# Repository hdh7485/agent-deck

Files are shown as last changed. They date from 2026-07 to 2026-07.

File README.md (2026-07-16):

# Agent Deck

Codex, Hermes, OMX, tmux 같은 AI 에이전트 작업을 물리적으로 제어하고 상태를 RGB로 표시하는 데스크톱 컨트롤러 프로젝트입니다.

이 프로젝트는 공개된 제품 경험을 참고하되, 공개되지 않은 OpenAI Micro의 회로·펌웨어·프로토콜을 추정하거나 복제하지 않습니다. 목표는 기능적으로 유사한 사용자 경험을 제공하는 독자 설계입니다.

## V1 범위

- PCB 고정형 MX 호환 기계식 키 12개, Kailh 핫스왑 소켓, 키별 다이오드. 터치 오른쪽 K11은 기본 2u 마이크/PTT 키
- 전체 12키 개별 RGB 상태 표시
- 클릭 가능한 로터리 엔코더 1개
- 낮은 원형 오목 캡을 씌운 5방향 디지털 내비게이션 스위치 1개
- 단일 원형 정전식 터치 패드 1개
- XIAO ESP32-S3 Plus와 XIAO nRF52840 Plus 비교 평가
- USB HID, Vendor HID, BLE HID 및 상태 통신 실험
- Codex/Hermes/OMX/tmux 상태를 정규화하는 PC 브리지
- USB 전원 우선 검증 후 1셀 Li-Po 평가

OLED나 LCD는 사용하지 않습니다. 모든 입력 부품은 브레드보드가 아니라 입력 PCB에 직접 실장합니다.

## 현재 기준 설계

V1은 공용 입력 PCB와 MCU별 어댑터 보드를 사용합니다. 입력 PCB에는 키 매트릭스, MCP23017, 내비게이션 스위치, 정전식 터치 IC, 엔코더, RGB LED 및 전원 보호 회로를 두고, 어댑터는 XIAO 보드별 핀·전원·USB 차이를 흡수합니다.

- 키 12개: 5핀 MX 호환 스위치, Kailh `CPG151101S11-16` 핫스왑 소켓, 다이오드를 포함한 4×4 매트릭스. K11은 호스트 음성 입력을 누르는 동안만 여는 기본 PTT 매핑
- MCP23017: 키 매트릭스, 5방향 스위치, 터치 출력 처리
- 엔코더 A/B/클릭: MCU 직접 연결
- 터치: AT42QT1010 계열 외부 IC 우선
- RGB: 5V 주소 지정 LED, 74AHCT1G125 레벨 시프터, 전류 제한 전원 스위치
- USB-C: V1에서는 장착한 XIAO의 온보드 USB-C를 케이스 밖으로 노출
- 배터리: 어댑터 측에서 각 XIAO의 충전·배터리 회로를 사용하고 공용 PCB에 충전기를 중복하지 않음

이 결정은 회로도 작성 전 공식 회로도 대조와 벤치 실험으로 다시 검증합니다.

## KiCad V1 엔지니어링 드래프트

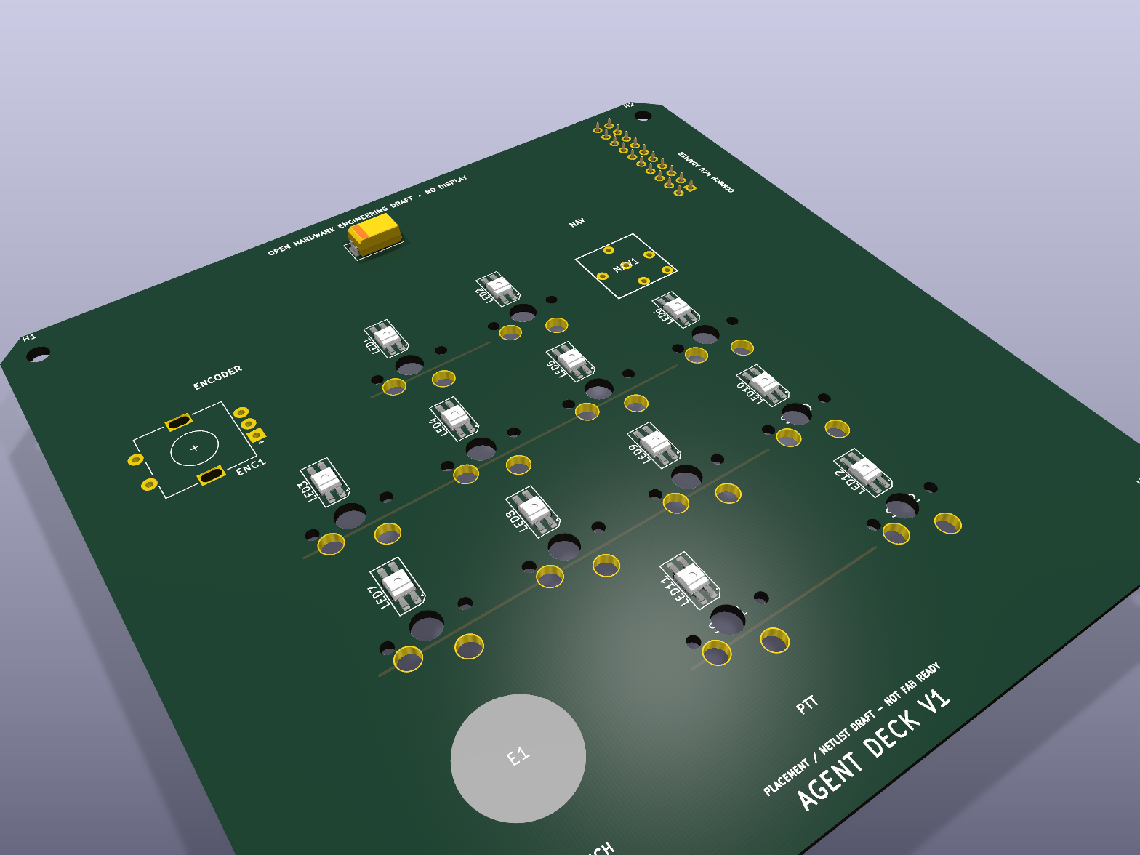
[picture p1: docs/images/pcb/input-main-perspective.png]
Agent Deck V1 common input PCB perspective


현재 저장소에는 다음 실제 KiCad 설계 소스가 있습니다.

- 공용 입력 PCB: 12키, 12다이오드, 키별 RGB 12개, MCP23017, EC11, 5방향 입력, AT42QT1010 터치, TPS2553 RGB 전류 제한, AHCT 레벨 시프터
- XIAO ESP32-S3 Plus 전용 어댑터
- XIAO nRF52840 Plus 전용 어댑터
- 세 보드의 블록 회로도와 재현 가능한 생성 스크립트

이 파일은 부품 배치와 전기 넷을 검토하기 위한 엔지니어링 드래프트입니다. 장거리 배선은 정확한 스위치·내비게이션·커넥터·플레이트 치수를 확정한 뒤 수동 라우팅하므로 아직 PCB 제작용 릴리스가 아닙니다. 현재 검증 결과와 남은 DRC 항목은 [KiCad 검증 기록](hardware/kicad/VALIDATION.md)에 있습니다.

## 3D 프린트 케이스 핏체크

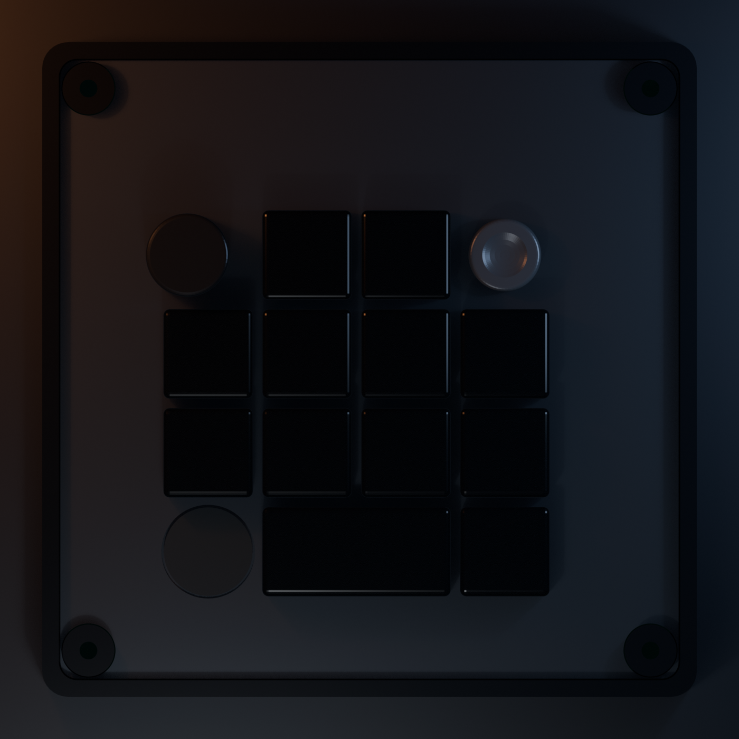
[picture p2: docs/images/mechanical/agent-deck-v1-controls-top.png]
Agent Deck V1 top control layout


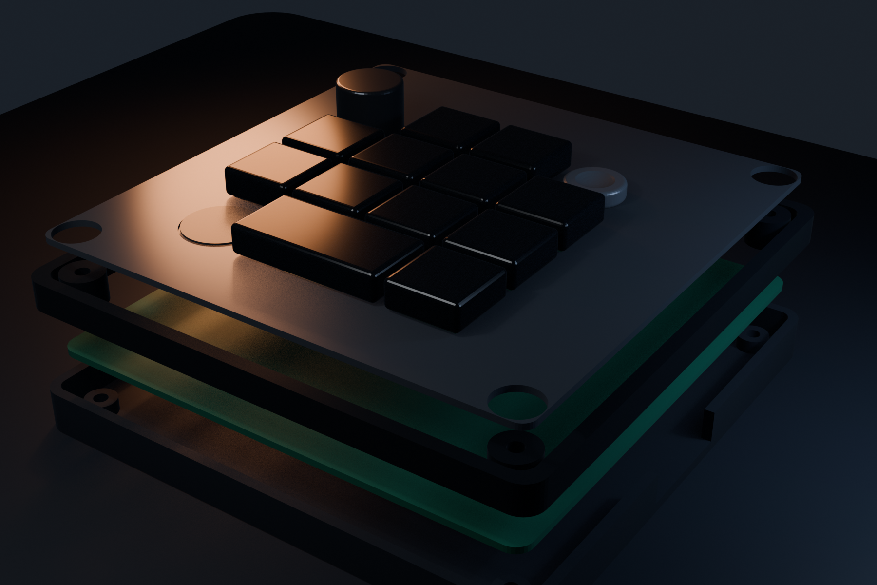
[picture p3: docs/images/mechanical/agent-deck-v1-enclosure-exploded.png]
Agent Deck V1 enclosure exploded view


현재 PCB 좌표에서 생성한 하판, 상부 베젤, 12키 1.5 mm MX 플레이트 STL이 `mechanical/exports/v1-fit-check/`에 있습니다. 공개 외형처럼 상단은 엔코더–키 2개–조이스틱, 하단은 터치–2u PTT–보조 키로 배치했습니다. 모든 키캡은 각인 없는 검정 반투명 스모크 재질을 의도하며, 1u와 2u 키를 19 mm 격자와 1.8 mm 명목 간격으로 정렬했습니다. 공용 PCB는 118 × 118 mm, 케이스 외형은 125.8 × 125.8 × 17.0 mm의 정사각형입니다. 정확한 2u 스태빌라이저·스위치·USB·배터리·터치 치수가 아직 확정되지 않았으므로 양산 케이스가 아니라 조립 간섭을 찾기 위한 출력용 초안입니다.

## 문서 지도

- [제품 요구사항](.omx/plans/prd-agent-deck-v1.md)
- [검증 계획](.omx/plans/test-spec-agent-deck-v1.md)
- [시스템 아키텍처](docs/architecture/system-architecture.md)
- [XIAO 핀 호환성](docs/hardware/pin-compatibility.md)
- [전기 설계 제안](docs/hardware/electrical-proposal.md)
- [부품·기구 결정 체크리스트](docs/hardware/design-inputs-checklist.md)
- [V1 프로토타입 BOM](docs/hardware/prototype-bom.csv)
- [장치 프로토콜](docs/protocol/device-protocol.md)
- [공식 자료 목록](docs/research/source-register.md)
- [KiCad 구조](hardware/kicad/README.md)
- [KiCad 검증 기록](hardware/kicad/VALIDATION.md)
- [펌웨어 구조](firmware/README.md)
- [PC 브리지 구조](bridge/README.md)
- [기구 설계 구조](mechanical/README.md)
- [3D 프린트 케이스 핏체크](mechanical/enclosure/README.md)

## 제작 순서

1. 두 MCU의 최소 펌웨어와 통신 경로를 개발 보드에서 검증
2. 공식 핀맵·회로도와 선택 부품 데이터시트로 회로도 작성
3. 입력 PCB와 MCU 어댑터 PCB 설계 및 DRC/ERC
4. 스위치 플레이트 설계
5. 케이스와 USB/안테나/배터리 간섭 검증
6. 조립 및 전기적 안전 검사
7. USB/BLE/입력/RGB/전력/재연결/위험 동작 E2E 테스트

## 상태

V1 공용 입력 PCB와 두 MCU 어댑터의 KiCad 엔지니어링 드래프트를 만들었고, 세 블록 회로도는 ERC를 통과했습니다. PCB는 배치·넷리스트 검토 단계이며 부품 규격을 잠근 뒤 수동 라우팅, DRC 정리, 플레이트/케이스 3D 간섭 검증을 진행해야 합니다. 펌웨어와 PC 브리지는 아직 구조 문서 단계입니다.

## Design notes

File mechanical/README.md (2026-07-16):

# Mechanical design structure

## Stack baseline

- Separate 1.5 mm MX switch/control plate for the V1 fit-check.
- Common input PCB, nominally 1.6 mm.
- MCU adapter below or beside the input PCB with the XIAO USB-C accessible from the enclosure.
- Enclosure support around encoder, navigation switch, USB connector, and other repeated-load parts.

## Proposed tree

```text
mechanical/
  references/      # manufacturer STEP/DXF with source notes
  plate/           # plate source and exports
  enclosure/       # top/bottom enclosure source and exports
  fixtures/        # assembly and touch/force test fixtures
  exports/         # release-only STEP/DXF/STL when versioned
```

## Locked constraints

- No OLED/LCD window.
- All keys, LEDs, encoder, navigation switch, and touch electrode originate from PCB coordinates.
- The plate or enclosure carries repeated encoder/navigation force instead of relying only on solder pads.
- RF antenna regions remain free of metal plate, battery, dense copper, and enclosure features that violate the board guidance.
- Reset/boot/SWD service access remains possible without destructive disassembly during V1.
- USB cable shell and strain envelope are modeled, not just the receptacle body.

## Dimensions required before CAD release

- Exact MX switch/keycap MPN, travel, and retention tolerance; family, 19 mm pitch, 14.2 mm cutout, and Kailh socket candidate are selected.
- Encoder shaft/body/tab/knob dimensions and target protrusion.
- Navigation switch body, cap, travel, and support surfaces.
- Touch diameter, overlay thickness, and finger clearance.
- Adapter connector stack height and XIAO component/antenna envelopes.
- Battery dimensions, swelling allowance, connector, and retention.
- Fastener diameter, insert/boss geometry, and assembly order.

Build a low-cost plate and enclosure fit check before committing to final material or finish.

## V1 printable fit-check

Agent Deck V1 top control layout

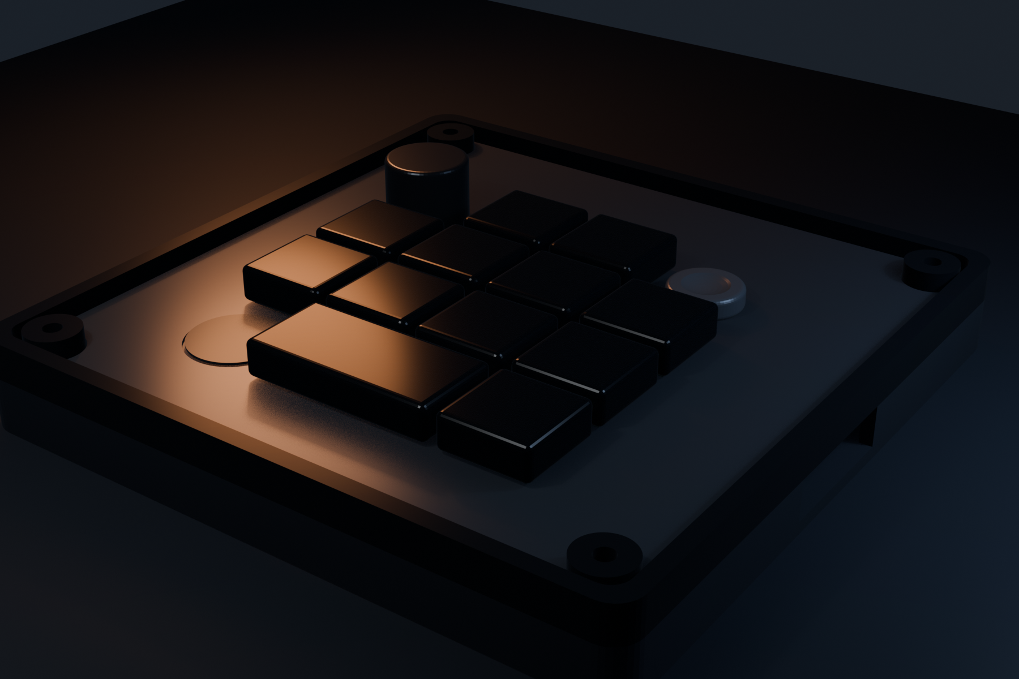
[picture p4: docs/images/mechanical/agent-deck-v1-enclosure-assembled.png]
Agent Deck V1 enclosure


The repository now includes a parametric Blender generator and three manifold STL fit-check parts:

- bottom PCB tray with four M3-aligned bosses;
- top bezel with a replaceable plate ledge;
- 1.5 mm MX plate with twelve 14.2 mm switch openings, encoder and navigation openings, and a 0.8 mm touch membrane.

The common PCB is 118 mm square and the body is 125.8 mm × 125.8 mm × 17.0 mm before controls. All keycaps use one blank black-smoke translucent render material. Their centers follow a 19 mm lattice; 17.2 mm 1u and 36.2 mm 2u envelopes retain a nominal 1.8 mm key-to-key gap. The low-profile C30 candidate has 2.1 mm nominal clearance to the plate underside, and the 1.85 mm Kailh socket body has 1.25 mm nominal clearance above the case floor. The navigation proxy uses a 14 mm round concave cap over an 11 mm RKJXM-class body. The broad side service slot is provisional because the adapter connector and XIAO USB orientation are not mechanically frozen.

Generate the STL files and preview images with:

```sh
blender --background --factory-startup --python mechanical/scripts/generate_enclosure.py
```

See `mechanical/enclosure/README.md` for print orientation, dimensions, and the explicit fit-check limitations.

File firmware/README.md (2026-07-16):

# Firmware architecture

V1 targets ESP-IDF on XIAO ESP32-S3 Plus and Zephyr/nRF Connect SDK on XIAO nRF52840 Plus. The domain behavior is shared; hardware and transport mechanics remain platform-specific.

## Proposed tree

```text
firmware/
  common/
    include/agent_deck/
    input/
    gestures/
    protocol/
    state/
    rgb/
    safety/
    tests/
  ports/
    esp32s3/
    nrf52840/
  boards/
    xiao_esp32s3_plus_adapter/
    xiao_nrf52840_plus_adapter/
  tools/
```

Directories are created when the selected build systems are bootstrapped; this document avoids committing empty generated projects before SDK versions are chosen.

## Common interfaces

- `clock`: monotonic milliseconds and deadlines.
- `input_bus`: MCP23017 register access and interrupt notification.
- `encoder`: timestamped raw A/B/click samples from direct GPIO.
- `rgb_sink`: bounded frame submission and power enable.
- `battery`: millivolt/charge status with board-specific validity flags.
- `transport`: connect, send envelope, receive envelope, MTU/capabilities.
- `storage`: validated small configuration records.
- `system`: reset reason, adapter identity, firmware/build identity.

The common layer must not include ESP GPIO numbers, Nordic pin names, RTOS task handles, or transport-specific connection objects.

## Shared modules

- Matrix scanner and debounce state machine.
- Navigation/contact debounce and simultaneous-input policy.
- Quadrature transition-table decoder.
- Touch gesture timing from one digital touch signal.
- Device-protocol encode/decode and sequence/epoch handling.
- Agent-state cache, selected-session state, heartbeat expiry.
- RGB state renderer with global power/current budget.
- Sensitive-action gesture classifier; authorization remains on the PC.

## Default K11 push-to-talk behavior

- Matrix position K11 is the default hold-to-talk control. It remains a normal debounced MX input and does not add a microphone or audio path to the device.
- Firmware emits both K11 press and release `KEY_EVENT` records. It does not synthesize a keyboard shortcut or decide which host application records audio.
- Reboot, transport loss, or heartbeat expiry clears the local pressed state; the bridge independently stops any active capture on the same failures.
- The default binding is configurable at the bridge, but the physical 2u keycap and microphone legend make the shipped V1 intent explicit.

## Platform responsibilities

### ESP32-S3 port

- ESP-IDF GPIO, I2C, timers, NVS, TinyUSB, BLE, optional Wi-Fi/WebSocket, and OTA spike.
- Native USB composite descriptors without taking GPIO19/20 for unrelated use.
- Wi-Fi is an optional transport and must not leak into the common state machine.

### nRF52840 port

- Zephyr GPIO, I2C, timers, settings, USB device stack, BLE HID/custom GATT, and DFU spike.
- NFC-pin configuration only if D14/D15 are ever used; baseline V1 leaves them out of the common interface.
- Low-power and reconnect measurements are part of the MCU selection evidence.

## Board definitions

Each adapter board definition declares semantic pins from `docs/hardware/pin-compatibility.md`, active levels, available battery sensing, transport capabilities, and service interfaces. Compile-time checks should fail if a required semantic pin is missing or assigned to D16.

## Test strategy

- Host-native unit tests for protocol, debounce, gestures, state expiry, and LED budget.
- Platform tests with fake I2C/input sources before hardware.
- On-device loopback for protocol and transport reconnect.
- Hardware-in-the-loop tests aligned with `.omx/plans/test-spec-agent-deck-v1.md`.

SDK versions and exact build commands remain a blocking decision; do not generate both projects until supported releases and CI host requirements are selected.

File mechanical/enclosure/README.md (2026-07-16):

# Agent Deck V1 enclosure fit-check

Status: printable mechanical fit-check, not a production enclosure release.

## Parts

| File | Purpose | Recommended print orientation |
| --- | --- | --- |
| `agent-deck-v1-bottom.stl` | PCB tray, M3 bosses, provisional side service opening | base flat on bed |
| `agent-deck-v1-top-bezel.stl` | perimeter bezel and replaceable-plate ledge | widest flat face on bed |
| `agent-deck-v1-mx-plate.stl` | 12-key MX control plate; K11 2u stabilizer geometry remains open | top face on bed for a clean touch membrane |

The files are under `mechanical/exports/v1-fit-check/`. Import as millimetres without scaling.

## Nominal dimensions

- PCB source envelope: 118.0 mm × 118.0 mm × 1.6 mm.
- Case body: 125.8 mm × 125.8 mm × 17.0 mm before keycaps and knobs.
- Wall/base: 2.4 mm.
- PCB bottom above case floor: 5.5 mm.
- Plate: 118.8 mm × 118.8 mm × 1.5 mm.
- MX openings: 14.2 mm square at the PCB's 19 mm pitch.
- Key stack: 5-pin MX-compatible switch holes with bottom-mounted Kailh `CPG151101S11-16` hot-swap sockets; 1.25 mm nominal socket-to-floor clearance.
- Touch feature: 18.0 mm recess with a provisional 0.8 mm membrane.
- All keycap centers use a 19.0 mm lattice. The 17.2 mm 1u and 36.2 mm 2u envelopes preserve a nominal 1.8 mm gap horizontally and vertically.
- Every keycap is rendered with the same blank black-smoke translucent finish. K11 retains its host-side hold-to-talk mapping without a microphone legend.
- K11 sits immediately right of the touch center at a 28.5 mm center pitch and is rendered as a 36.2 mm-wide 2u keycap. Its MX switch and per-key RGB remain single matrix/LED positions.
- Nominal touch-to-K11 separation: 12.4 mm to the centered MX plate opening and 1.4 mm to the 2u keycap envelope.
- The exact 2u keycap and stabilizer family are not selected. The current plate keeps only the center MX opening, so stabilizer cutouts/PCB holes must be added from the selected manufacturer's drawing before fabrication.
- C30 candidate clearance to the plate underside: 2.1 mm nominal.
- Navigation control: provisional ALPS `RKJXM1015004` 11 mm body, 12 mm plate opening, and 14 mm low round concave cap.
- Side service opening: 26.0 mm × 7.6 mm, provisional.

The machine-readable dimensions and manifold results are in `mechanical/exports/v1-fit-check/dimensions.json`.

## Prototype print settings

- PLA or PETG for the first fit check.
- 0.20 mm layer height.
- At least three perimeters and four top/bottom layers.
- 20% infill is adequate for the dimension coupon; increase around the control plate if flex is observed.
- No supports should be required in the documented orientation, but slicer bridge preview remains mandatory.
- Use M3 fasteners only after measuring printed hole shrinkage; the 3.4 mm model holes are clearance candidates, not a guaranteed printer profile.

## Blocking checks before calling this an enclosure revision

- Select the exact MX switch, 1u/2u keycaps, K11 stabilizer, encoder, and knob; verify the selected Kailh socket and RKJXM candidate samples.
- Confirm the plate-to-PCB stack against physical switch samples.
- Lock the MCU adapter connector orientation and replace the broad service slot with the exact USB-C cable envelope.
- Add the selected battery volume, swelling allowance, retention, and cable path.
- Print touch coupons around 0.6, 0.8, 1.0, and 1.2 mm membrane thickness and measure recognition during RGB switching and charging.
- Check antenna clearance using the exact XIAO board, adapter, plate material, fasteners, and battery.
- Perform a first-article assembly before adding snaps, heat-set inserts, cosmetic textures, or production tolerances.

## Regeneration

The authoritative source is `mechanical/scripts/generate_enclosure.py`. It creates all three STL files, assembled/exploded preview images, `dimensions.json`, and an ignored Blender artifact for inspection.

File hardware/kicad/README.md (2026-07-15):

# KiCad project structure

Create separate KiCad projects so common-input changes and board-specific adapter changes remain reviewable.

```text
hardware/kicad/
  input-main/
    input-main.kicad_pro
    input-main.kicad_sch
    input-main.kicad_pcb
  adapters/
    xiao-esp32s3-plus/
      xiao-esp32s3-plus.kicad_pro
      xiao-esp32s3-plus.kicad_sch
      xiao-esp32s3-plus.kicad_pcb
    xiao-nrf52840-plus/
      xiao-nrf52840-plus.kicad_pro
      xiao-nrf52840-plus.kicad_sch
      xiao-nrf52840-plus.kicad_pcb
  libraries/
    agent-deck.kicad_sym
    agent-deck.pretty/
    3dmodels/
  templates/
  scripts/
```

## Main schematic hierarchy

- `00_interface`: semantic adapter connector, test points, board identity.
- `10_keys`: 13 switches, diodes, 4×4 matrix.
- `20_io_expander`: MCP23017, address/reset, I2C, interrupts.
- `30_controls`: encoder, navigation, touch controller/electrode.
- `40_rgb`: LEDs, buffer, data resistor, decoupling.
- `50_power`: RGB load switch/current limit, rail test points, optional battery-RGB experiment kept isolated.

## Adapter schematic hierarchy

- XIAO symbol/footprint from the matching official Seeed design resources.
- Semantic connector mapping.
- USB-C access and enclosure reference.
- Battery connector/board charger interface.
- Reset/boot/debug/SWD test pads.
- Antenna keep-out and mechanical outline.
- Adapter identity.

## Library policy

- Copy only project-used symbols/footprints into the project library when licensing permits, preserving attribution and source revision.
- Verify every pad number and courtyard against the selected component drawing.
- Do not trust community footprints for XIAO bottom pads, hot-swap sockets, encoders, or navigation switches without a dimension check.
- Keep generated fabrication outputs out of Git unless a release process explicitly snapshots them.

## Coordinate contract

The common PCB origin, key centers, plate origin, mounting holes, adapter connector, USB datum, encoder axis, navigation axis, and touch center form a versioned mechanical interface. Mechanical CAD imports these coordinates; it must not re-create them by eye.

## Gates

No board is ordered until exact components pass `docs/hardware/design-inputs-checklist.md`, ERC/DRC pass, official XIAO mappings are rechecked, 3D interference is reviewed, and first-article power tests are prepared.

## Generated V1 draft

The repository now contains all three KiCad projects described above. The main PCB has complete component placement and electrical net assignments, plus safe local matrix routing. Long routes remain as ratsnest until the blocking mechanical selections are locked. This is deliberate: the first automatic long-route experiment produced real crossings and was discarded rather than hidden with exclusions.

Regenerate with KiCad 10.0.4's bundled Python:

```sh
/opt/homebrew/Caskroom/kicad/10.0.4/KiCad/KiCad.app/Contents/Frameworks/Python.framework/Versions/3.9/bin/python3 \
  hardware/kicad/scripts/generate_design.py
```

The generator transcribes the XIAO Plus physical land pattern from Seeed's official Plus baseboard resource and uses the conservative semantic mapping in `docs/hardware/pin-compatibility.md`. It does not claim that the two MCU boards are electrically interchangeable.

See `VALIDATION.md` for the fresh ERC/DRC evidence and the explicit fabrication stop condition.

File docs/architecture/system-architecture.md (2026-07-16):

# System architecture

## Scope

Agent Deck is a physical controller and status surface for local AI-agent workflows. It does not embed Codex, Hermes, OMX, or tmux. A host bridge owns process discovery, session identity, state interpretation, and authorization; the device owns tactile input, local feedback, transport, and offline-safe behavior.

## Top-level flow

```mermaid
flowchart LR
    subgraph Device[Physical device]
        K[12-key matrix] --> IOX[MCP23017]
        J[5-way navigation] --> IOX
        T[Circular electrode] --> TC[Touch controller] --> IOX
        E[Encoder A/B/click] --> HAL[Platform HAL]
        IOX --> HAL
        HAL --> CORE[Shared event/state core]
        CORE --> RGB[12-key RGB renderer]
        CORE <--> TR[USB / BLE / Wi-Fi transports]
    end

    TR <--> BRIDGE[PC bridge]
    BRIDGE <--> CODEX[Codex adapter]
    BRIDGE <--> HERMES[Hermes adapter]
    BRIDGE <--> OMX[OMX adapter]
    BRIDGE <--> TMUX[tmux adapter]
    BRIDGE <--> UI[Optional local config API]
```

## Responsibility boundaries

### Common input PCB

- Owns the physical layout of all controls.
- Scans low-speed controls through MCP23017.
- Conditions encoder, touch, RGB, and power signals.
- Exposes only semantic signals to the adapter connector.
- Contains no assumptions about ESP32 or nRF GPIO numbering.

### MCU adapter

- Maps semantic signals to one XIAO board revision.
- Owns board-specific reset/boot/debug access, USB placement, antenna keep-out, and battery connection.
- Prevents use of reserved battery, USB, NFC, JTAG, or strapping signals unless explicitly designed.
- Provides identification straps or firmware build identity so the common firmware configuration cannot silently target the wrong board.

### Firmware common core

- Converts raw inputs to stable semantic events.
- Maintains selected agent/session display state and transport health.
- Implements protocol framing, capability negotiation, sequence handling, and stale-state expiry.
- Applies local brightness/current limits and never invents host authorization.

### Platform ports

- ESP32-S3: ESP-IDF GPIO/I2C/TinyUSB/BLE/Wi-Fi implementation.
- nRF52840: Zephyr/nRF Connect SDK GPIO/I2C/USB/BLE implementation.
- Both expose the same interfaces described in `firmware/README.md`.

### PC bridge

- Discovers and tracks sessions through isolated integration adapters.
- Normalizes upstream state to the device state model.
- Routes input events to the selected session.
- Validates session identity and state before any sensitive action.
- Persists user mappings and emits an audit record for guarded actions.

## State model

The minimum host-to-device state set is:

- `idle`
- `running`
- `waiting_approval`
- `waiting_input`
- `completed`
- `failed`
- `disconnected` for device-local fail-safe rendering

`disconnected` is not an upstream agent state. Firmware enters it when the bridge heartbeat expires.

## Action model

Inputs produce semantic action intents such as `select_next_session`, `approve`, `reject`, or `interrupt`. The device does not decide whether an agent command is valid. The bridge resolves the current selected session, verifies the required state, applies confirmation policy, executes through the owning integration adapter, and returns an acknowledgement.

```mermaid
sequenceDiagram
    participant D as Device
    participant B as Bridge
    participant A as Agent adapter
    D->>B: ACTION_INTENT(approve, session_id, gesture)
    B->>B: Verify session, state, policy, sequence
    alt authorized
        B->>A: approve(session_id)
        A-->>B: result
        B-->>D: ACTION_RESULT(success/failure)
    else rejected
        B-->>D: ACTION_RESULT(policy_rejected)
    end
```

## Transport strategy

- USB HID is the basic host-control compatibility path.
- Vendor HID is the preferred V1 bidirectional USB message path.
- BLE HID plus a custom GATT service provides the wireless equivalent.
- ESP32-S3 Wi-Fi WebSocket is an experiment behind the same protocol adapter, not a required dependency for device semantics.
- CDC serial is reserved for diagnostics and bring-up; product behavior must not require parsing console text.

## Failure behavior

- Bridge heartbeat expiry clears selected-action eligibility and shows the disconnected RGB pattern.
- Duplicate or stale sequence numbers are ignored and acknowledged as such.
- Reconnection starts with capability negotiation and a complete state snapshot.
- Pending confirmations are cancelled by session changes, transport changes, device reset, or bridge restart.
- The device never replays buffered sensitive actions after reconnection.

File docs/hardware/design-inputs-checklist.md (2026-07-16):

# Schematic-freeze input checklist

Do not start the release schematic until every blocking item has an owner, value, source, and review state. Items marked `measure` require a physical sample or coupon.

## Product and control map

- [ ] Name and physical location of all 12 keys.
- [x] Reserve K11 beside the touch control as the default hold-to-talk key; remapping remains a bridge policy.
- [ ] Optical behavior and state priority for all 12 RGB keys.
- [ ] Default encoder rotation/click actions and modifier behavior.
- [ ] Navigation direction/center actions and simultaneous-contact policy.
- [ ] Touch tap, double-tap, and long-press timing targets.
- [ ] Which actions are sensitive and their confirmation gestures.
- [ ] Host OS support order and minimum Codex/Hermes/OMX/tmux versions or capability assumptions.

## Mechanical switches and keycaps

- [x] MX family selected for the V1 fit-check; Choc overlap explicitly excluded.
- [x] Hot-swap socket candidate locked to Kailh `CPG151101S11-16` with official drawing.
- [ ] Exact MX switch MPN and manufacturer drawing selected.
- [ ] Key pitch, row/column geometry, rotation, and plate cutout locked.
- [ ] Keycap profile, height, translucent regions, and collision envelope.
- [ ] Plate thickness and PCB-to-plate spacing verified from the selected switch/socket stack.
- [ ] Select the exact 2u K11 keycap and stabilizer, then add manufacturer-drawing plate/PCB geometry and service clearance.
- [ ] Per-key diode package, direction, and assembly access.

## Encoder

- [ ] Exact MPN, detent/pulse count, shaft type/diameter/length, bushing, and mounting tabs.
- [ ] Knob diameter/height and finger clearance.
- [ ] Encoder body height relative to PCB, plate, and enclosure.
- [ ] Maximum actuation torque/force transferred to plate or enclosure support.
- [ ] Debounce network values selected after scope measurement.

## Navigation switch

- [ ] Validate the ALPS Alpine `RKJXM1015004` candidate and transcribe every official terminal/support hole; its 8-direction motion is interpreted as four cardinal contacts plus simultaneous-contact diagonals.
- [ ] Center/direction actuation force, travel, cap dimensions, and mounting tab geometry.
- [x] V1 exterior cap envelope set to a provisional 14 mm low round concave profile.
- [ ] Plate/enclosure support strategy.
- [ ] Firmware rule for opposing or diagonal simultaneous contacts.

## Touch

- [ ] Touch controller exact MPN/package and official reference circuit.
- [ ] Electrode diameter and copper layer.
- [ ] Overlay material, dielectric constant if available, and thickness.
- [ ] Ground keep-out/hatch, guard routing, and adjacent LED/USB clearance.
- [ ] Sensitivity component range and tuning footprint.
- [ ] `measure`: coupon performance with dry finger, humid finger, grounded enclosure contact, USB activity, RGB switching, and charging.
- [ ] Swipe explicitly excluded unless a multi-electrode redesign is approved.

## RGB and optics

- [ ] Exact LED MPN, voltage/current limits, package drawing, pinout, reflow limits, and data timing.
- [ ] Translucent keycap or light-pipe geometry and LED-to-key alignment.
- [ ] Maximum useful brightness measured in the actual key stack.
- [ ] Firmware total-current budget and per-state brightness table.
- [ ] Level shifter and current-limited load-switch MPNs and equations.
- [ ] Per-LED and bulk capacitor values/voltage ratings.
- [ ] Battery-only RGB requirement: off, reduced, or full; if non-off, boost/power-mux design approved.

## Common PCB and adapter connector

- [ ] Adapter connector family, exact mating pair, pin count, pitch, stack height, insertion cycles, current rating, and retention.
- [ ] Connector pinout includes multiple ground contacts and no unsafe hot-plug assumption.
- [ ] Semantic net direction, voltage, reset level, and owner documented for every pin.
- [ ] Adapter identity method selected.
- [ ] Service access for XIAO reset/boot/SWD/UART defined.
- [ ] XIAO USB-C cable envelope and enclosure opening measured.
- [ ] Both RF antenna keep-outs modeled with the actual battery and plate material.

## Power and battery

- [ ] Exact purchased XIAO revisions and matching official schematics captured in test evidence.
- [ ] Protected one-cell Li-Po capacity, dimensions, connector, wire exit, and maximum charge/discharge ratings.
- [ ] Battery connector polarity permanently documented; never trust wire color alone.
- [ ] Each XIAO onboard charger behavior, current, thermal case, and power-path limitation verified.
- [ ] No charger duplication or USB/battery back-feed path.
- [ ] 3.3 V common-load budget and XIAO regulator margin calculated.
- [ ] USB worst-case and declared current budget calculated.
- [ ] Battery voltage measurement divider/enable sequence verified for both boards.
- [ ] Test points for ground, VBUS, 3V3, battery, and RGB rail included.
- [ ] Power switch or shipping-mode requirement decided.

## PCB fabrication and assembly

- [ ] Board thickness, copper weight, finish, minimum rules, via rules, and panel constraints.
- [ ] Hot-swap/socket and connector assembly side locked.
- [ ] All user-load parts have mechanical support beyond fragile pads.
- [ ] Touch electrode manufacturing notes and solder-mask behavior specified.
- [ ] RF and antenna regions have explicit keep-outs on all copper and mechanical layers.
- [ ] Fiducials, tooling, test points, revision labels, and pin-1 marks included.
- [ ] Hand assembly versus SMT assembly split and package-size floor decided.

## Firmware and protocol inputs

- [ ] ESP-IDF and Zephyr/nRF Connect SDK baseline versions selected from supported releases.
- [ ] USB composite descriptor layout and report IDs frozen.
- [ ] BLE services, characteristics, MTU assumptions, bonding, and security policy frozen.
- [ ] Protocol major/minor compatibility and capability bits frozen.
- [ ] Heartbeat/stale-state timeout and reconnection rules frozen.
- [ ] Device update/recovery strategy documented for both boards.

## Release evidence

- [ ] Official source register complete for every selected active part.
- [ ] BOM alternatives reviewed for pin/footprint/firmware compatibility; none assumed drop-in without evidence.
- [ ] ERC/DRC pass and waivers reviewed.
- [ ] 3D stack interference review complete.
- [ ] First-article bring-up checklist prepared from `.omx/plans/test-spec-agent-deck-v1.md`.

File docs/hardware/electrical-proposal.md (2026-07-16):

# V1 electrical proposal

This is a design baseline, not a released schematic. Exact footprints, ratings, thresholds, and power cases require manufacturer-data-sheet review and bench verification.

## Block diagram

```mermaid
flowchart TB
    X[XIAO MCU adapter] -->|3V3, I2C, INT, encoder, RGB control| C[Common input PCB]
    USB[Onboard USB-C] --> X
    BAT[Protected 1-cell Li-Po] --> X

    subgraph C[Common input PCB]
        M[12 keys + 12 diodes\n4x4 matrix] --> IOX[MCP23017 @ 3.3V]
        NAV[5-way digital nav] --> IOX
        PAD[Circular copper electrode] --> TOUCH[AT42QT1010-class touch IC] --> IOX
        ENC[EC11 A/B/click] --> ECOND[RC/ESD optional conditioning] --> X
        IOX -->|INT| X
        X -->|RGB_DATA| LSH[74AHCT1G125]
        VBUS[VBUS_5V] --> LIM[Current-limited load switch]
        X -->|RGB_PWR_EN| LIM
        LIM --> LED[12 addressable RGB LEDs]
        LSH -->|330R series| LED
    end
```

## Key matrix

- Arrange 12 switches in a 4-row × 4-column logical matrix; leave four locations unpopulated.
- Add one 1N4148W-class diode per key with a single documented current direction.
- Put all eight row/column lines on MCP23017 port A: `GPA0..3 = ROW0..3`, `GPA4..7 = COL0..3`.
- Scan one driven row at a time and read columns. Exact active polarity is fixed by the diode orientation and recorded in the schematic notes.
- V1 uses centered 5-pin MX-compatible switch holes and one bottom-mounted Kailh `CPG151101S11-16` socket per key. It does not use a universal MX/Choc overlap.
- Keep the reverse-mount RGB package south of each stem and the socket body north. K11 uses the same electrical footprint at a 29 mm touch-to-key center pitch, but carries a 2u keycap and defaults to host-side push-to-talk.
- The 2u K11 does not consume another matrix input or RGB channel: it remains one MX switch, one diode, and one addressable LED. Press and release are both reported so the bridge can bound host microphone capture.
- The exact switch MPN, keycaps, and K11 stabilizer remain open, but the V1 fit-check plate is now 14.2 mm MX at 1.5 mm nominal thickness. Add stabilizer geometry from the selected manufacturer drawing, then verify socket land pattern, PCB thickness, plate latching, insertion force, and touch clearance with physical samples before fabrication.

## MCP23017 allocation

| MCP23017 pin | Net | Use |
| --- | --- | --- |
| GPA0–GPA3 | `ROW0`–`ROW3` | Key matrix drive |
| GPA4–GPA7 | `COL0`–`COL3` | Key matrix sense |
| GPB0 | `NAV_UP_N` | Navigation input |
| GPB1 | `NAV_DOWN_N` | Navigation input |
| GPB2 | `NAV_LEFT_N` | Navigation input |
| GPB3 | `NAV_RIGHT_N` | Navigation input |
| GPB4 | `NAV_CENTER_N` | Navigation input |
| GPB5 | `TOUCH_OUT` | Touch controller digital output |
| GPB6–GPB7 | `SPARE_IOX0/1` | Test pads, uncommitted |
| INTB | `IOX_INT` | Navigation/touch interrupt to MCU |
| INTA | DNP/test pad | Optional matrix/diagnostic interrupt |

Use 3.3 V supply, local 100 nF decoupling, address straps with explicit resistors, I2C pull-ups sized after bus capacitance is known, and a connector-visible reset/test strategy. V1 keeps the expander because it makes the common adapter interface small and deterministic. V2 may remove it if measured latency, sleep current, cost, or availability outweighs the layout benefit.

## Navigation switch choice

### Direct digital inputs through MCP23017 — recommended

Advantages:

- No ADC-reference or threshold differences between MCUs.
- Simple per-direction diagnostics and deterministic center event.
- Clear handling of simultaneous contacts.
- No extra MCU pins because the expander already exists.

Costs:

- Five expander pins and a larger switch footprint.
- I2C sampling/interrupt latency, which must be measured.

### Resistor ladder to one ADC

Advantages:

- One MCU analog input and fewer connector signals if no expander is used.

Costs:

- Thresholds vary with resistor tolerance, ADC gain/reference, supply, noise, and board calibration.
- Simultaneous directions may create ambiguous voltages.
- ESP and Nordic ADC behavior requires separate calibration.
- D16 cannot be reused because it is reserved for battery sensing.

Decision: use five digital contacts on MCP23017 for V1. Keep a resistor-ladder test coupon only if future cost or pin pressure justifies it.

The current mechanical candidate is ALPS Alpine `RKJXM1015004`, an official 11 mm × 11 mm × 6.6 mm through-hole stick switch with center push. It can expose cardinal directions as separate digital contacts while diagonal motion becomes simultaneous cardinal contacts. The PCB still labels its land pattern as provisional until every official terminal and support hole is transcribed and checked. A separate 14 mm low round concave cap provides the desired exterior feel; it does not imply that the public reference product uses the same internal switch.

## Encoder

- Use an EC11-class encoder with metal mounting tabs and a locked shaft height.
- Connect A, B, and click directly to `ENC_A`, `ENC_B`, and `ENC_SW` on the adapter.
- Provide optional DNP RC footprints so edge shaping can be tuned after scope measurements.
- Use Schmitt-capable GPIO input configuration where available and decode quadrature with a transition table, not independent edge counters.
- The plate or enclosure must support actuation torque; solder pads are not the only mechanical restraint.

## Touch

- Use one round copper electrode with a keep-out from noisy RGB and USB traces.
- Use an AT42QT1010-class one-channel controller to keep MCU behavior common.
- Connect its digital output to MCP23017 GPB5.
- Implement tap, long press, and double tap from timestamps in the common firmware layer.
- Do not claim swipe recognition from one electrode. Swipe requires a later multi-electrode and controller redesign.
- Add a tuning/test coupon for electrode diameter, overlay thickness, ground hatch, and sensitivity component before freezing the enclosure.

## RGB and power

- Twelve SK6812 Mini-E-compatible addressable RGB LEDs, one per key, are the optical baseline; verify exact package and footprint before release layout.
- Feed data through a 74AHCT1G125-class 3.3 V-to-5 V buffer. Keep output enable in a defined state.
- In the V1 draft, power the buffer from `VBUS_5V` and use an MMBT3904-class inverter so the active-low output enable follows `RGB_PWR_EN`: reset/default-low disables both the TPS2553 and the data driver.
- Place approximately 330 ohm in series with the first LED data input and route the chain away from the touch electrode.
- Place 100 nF at each LED, one 10 uF X7R local capacitor on the LED rail, and a low-profile board-entry bulk capacitor; final values follow transient and DC-bias measurements.
- Replace the tall 470 uF radial draft part with Panasonic `10TPF150ML` as the provisional low-profile bulk candidate: 150 uF, 10 V, and 7.3 mm × 4.3 mm × 2.8 mm according to Panasonic's official model table. The KiCad draft uses a conservative EIA-7343-31 land pattern; the exact Panasonic recommended land pattern and polarity marking remain fabrication blockers.
- Feed the LED rail through a current-limited load switch with default-off enable. Candidate families include TPS2553 or AP22653; exact current-set value is selected after LED current measurements.
- The current KiCad draft uses TPS2553DBVR with a 232 kOhm 1% `ILIM` candidate, approximately 117 mA typical from TI's equation. This is a starting point, not a guaranteed maximum; tolerance and transient testing decide the release value.
- Calculate traces and connectors for the selected LED's data-sheet worst case, but enforce a lower aggregate firmware budget. The provisional product budget remains 120 mA total across all 12 LEDs, 10 mA average per LED when all are active, until optical and transient testing justify another value.
- Increasing the chain from six to twelve LEDs consumes no additional MCU GPIO: `RGB_DATA` and `RGB_PWR_EN` remain the only MCU-side RGB signals. Firmware must scale or clamp a complete frame before transmission rather than relying only on the load switch.
- On USB power, `VBUS_5V` supplies the LED switch. In initial battery-only testing, RGB may remain disabled. Full battery-mode RGB requires a separately reviewed boost/power-mux design and is not silently powered from an undefined XIAO 5 V pin.

## Power partition

- The common PCB consumes 3.3 V for MCP23017, touch, and logic.
- Add one 10 uF X7R local bulk capacitor on the 3.3 V rail in addition to device-level 100 nF decoupling; verify effective capacitance at the actual DC bias.
- Each adapter owns its XIAO battery pads, charge behavior, reset/boot, and USB placement.
- The common PCB must not add a second Li-Po charger while the XIAO charger is in circuit.
- Use a protected cell and keyed connector after polarity is locked.
- Provide current measurement points for total device, RGB rail, and 3.3 V logic.
- First power-up always uses a current-limited bench supply with the XIAO removed, then with one adapter installed.

## Protection and layout provisions

- Add ESD protection where external metal or connector exposure warrants it; exact parts depend on connector topology.
- Add series/DNP footprints on long or edge-sensitive signals that are difficult to rework after PCB assembly.
- Respect both XIAO RF antenna keep-outs and keep copper, battery, plate metal, and fast LED edges away from the antenna region.
- Keep touch sense routing short, guarded as the touch IC recommends, and separated from USB/RGB/power-switch nodes.
- Give encoder and navigation mounting tabs mechanical copper and keep-out treatment according to their data sheets.

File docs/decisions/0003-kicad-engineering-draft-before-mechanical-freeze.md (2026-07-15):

# ADR-0003: Keep the first KiCad revision as a placement and netlist engineering draft

Status: accepted for V1 prototype planning  
Date: 2026-07-16

## Decision

Create the common input PCB and both XIAO adapter projects now, but stop before release routing. The draft fixes the functional circuit, semantic connector, footprint candidates, board envelope, and control placement. Long traces remain unrouted until the switch/socket, five-way navigation part, adapter connector stack, touch overlay, plate, and enclosure datums are locked.

## Drivers

- A real KiCad model exposes footprint, keep-out, power, and connector problems earlier than prose alone.
- Routing around provisional mechanical parts would create false confidence and expensive rework.
- The two XIAO candidates must remain isolated behind identical semantic connectors without asserting pin compatibility.
- A rendered board is useful for layout review even when it is explicitly marked not fabrication-ready.

## Rejected alternatives

- Automatically complete long routing before mechanical freeze: the first experiment produced genuine crossings and was removed.
- Suppress all DRC findings: this would hide the reverse-mount LED cutout and under-key courtyard decisions that still need review.
- Copy a product teardown or unpublished design: outside the independent functional-design boundary.

## Consequences

- The repository has reviewable KiCad source and images now.
- ERC can validate the block schematics, while DRC records the exact open routing and footprint-review debt.
- Gerber generation and board ordering remain blocked until the mechanical checklist and final routing gates pass.

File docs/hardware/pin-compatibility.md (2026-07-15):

# XIAO Plus pin compatibility baseline

## Conclusion

The two Plus boards share many D-pin positions, but they are not drop-in electrical equivalents. V1 may use a conservative common subset through separate adapter boards. It must not connect every similarly named pad directly to the common input PCB.

This table was prepared from Seeed Studio's official board wiki and schematics, then cross-checked against the Espressif ESP32-S3 and Nordic nRF52840 official pin documentation. Exact purchased board revision must be checked again before schematic release.

## Position-by-position comparison

| XIAO position | ESP32-S3 Plus chip pin | nRF52840 Plus chip pin | Conservative shared use | V1 policy |
| --- | --- | --- | --- | --- |
| D0 | GPIO1, ADC | P0.02, AIN0 | Digital GPIO, ADC on both | `RGB_DATA` output |
| D1 | GPIO2, ADC | P0.03, AIN1 | Digital GPIO, ADC on both | `IOX_INT` input |
| D2 | GPIO3, ADC, ESP strapping/JTAG-source pin | P0.28, AIN4 | Digital/ADC electrically possible, boot semantics differ | Leave unconnected by default |
| D3 | GPIO4, ADC | P0.29, AIN5 | Digital GPIO, ADC on both | `RGB_PWR_EN` output with external default-off pull |
| D4 | GPIO5, I2C SDA, ADC | P0.04, I2C SDA, AIN2 | I2C SDA | `I2C_SDA` |
| D5 | GPIO6, I2C SCL, ADC | P0.05, I2C SCL, AIN3 | I2C SCL | `I2C_SCL` |
| D6 | GPIO43, UART TX | P1.11, UART TX | Digital GPIO/UART | Optional debug TX/test pad |
| D7 | GPIO44, UART RX | P1.12, UART RX | Digital GPIO/UART | Optional debug RX/test pad |
| D8 | GPIO7, SPI SCK, ADC | P1.13, SPI SCK | Digital GPIO/SPI; ADC only on ESP side | `ENC_A` input |
| D9 | GPIO8, SPI MISO, ADC | P1.14, SPI MISO | Digital GPIO/SPI; ADC only on ESP side | `ENC_B` input |
| D10 | GPIO9, SPI MOSI, ADC | P1.15, SPI MOSI | Digital GPIO/SPI; ADC only on ESP side | `ENC_SW` input |
| D11 | GPIO38; Seeed table says ADC but Espressif does not list an ADC channel | P0.15/I2S_SD; Seeed table says ADC but Nordic does not name it AIN | Digital GPIO only pending discrepancy resolution | Adapter spare, no analog claim |
| D12 | GPIO39, JTAG MTCK | P0.19/I2S_SCK | Digital GPIO, board-specific debug/peripheral roles | Adapter spare |
| D13 | GPIO40, JTAG MTDO | P1.01/I2S_WS | Digital GPIO, board-specific debug/peripheral roles | Adapter spare |
| D14 | GPIO41, JTAG MTDI | P0.09, NFC1/UART1 RX | Digital use requires board-specific configuration | Avoid on common PCB |
| D15 | GPIO42, JTAG MTMS | P0.10, NFC2/UART1 TX | Digital use requires board-specific configuration | Avoid on common PCB |
| D16 | GPIO10, board `ADC_BAT` | P0.31/AIN7, board battery sense | Battery sensing only; circuitry and enable semantics differ | Reserved, never generic output |
| D17 | GPIO13 | P1.03/SPI1 SCK | Digital GPIO | Optional adapter-local use |
| D18 | GPIO12 | P1.05/SPI1 MISO | Digital GPIO | Optional adapter-local use |
| D19 | GPIO11 | P1.07/SPI1 MOSI | Digital GPIO | Optional adapter-local use |

## Power and USB

| Function | ESP32-S3 Plus | nRF52840 Plus | Rule |
| --- | --- | --- | --- |
| VBUS/5V | USB-derived 5 V; Seeed documents special care for external injection | USB-derived 5 V/power pin | Treat as adapter power input, not a generic bidirectional rail |
| 3V3 | Regulated board output | Regulated board output | Common low-power logic rail only after current-budget review |
| Battery | Onboard charge/power circuit, board `ADC_BAT` on D16 | Onboard charge circuit, read enable plus D16 battery ADC path | Battery connector and sensing stay adapter-specific |
| USB | Native USB is wired to the onboard USB-C; relevant USB pads are board-specific | Native USB is wired to the onboard USB-C; bottom-pad routing must be checked from schematic | V1 exposes the onboard connector instead of adding a second connector |
| Reset/boot | ESP `CHIP_PU`, boot strap GPIO0; GPIO3 is also a strap | nRF reset/bootloader behavior and SWD | Expose adapter-specific service pads/buttons |

## Proposed common adapter interface

| Semantic signal | Default XIAO position | Direction at MCU | Notes |
| --- | --- | --- | --- |
| `RGB_DATA` | D0 | Output | Drives 74AHCT1G125 input, not LED directly |
| `IOX_INT` | D1 | Input | MCP23017 open-drain interrupt with 3.3 V pull-up |
| `RGB_PWR_EN` | D3 | Output | External pull-down keeps LED power off during reset |
| `I2C_SDA` | D4 | Bidirectional | MCP23017 bus, 3.3 V pull-up on common PCB |
| `I2C_SCL` | D5 | Output/open-drain | Same bus |
| `UART_TX_DBG` | D6 | Output | Optional test pad, not required in product mode |
| `UART_RX_DBG` | D7 | Input | Optional test pad, not required in product mode |
| `ENC_A` | D8 | Input | Direct MCU GPIO, hardware/software debounce study |
| `ENC_B` | D9 | Input | Direct MCU GPIO |
| `ENC_SW` | D10 | Input | Direct MCU GPIO |
| `3V3` | 3V3 | Power | MCP23017, touch IC, logic side of control circuits |
| `VBUS_5V` | 5V | Power | USB-mode RGB source only in baseline V1 |
| `GND` | GND | Power | Multiple connector contacts preferred |

D2 and D11–D19 are not required by the common PCB. Adapter revisions may use them only after documenting the board-specific reason.

## Required bench checks

1. Verify no common-PCB pull or capacitance changes ESP32-S3 boot behavior.
2. Verify MCP23017 interrupt wake behavior on both MCU sleep implementations.
3. Verify encoder counts on D8–D10 while USB/BLE traffic and RGB updates are active.
4. Verify D16 battery reading with the exact official board revision and documented enable sequence.
5. Verify the onboard USB-C connector can support the intended composite descriptors on both firmware stacks.

## Sources

See `docs/research/source-register.md`. Source conflict resolution is intentionally conservative: if a board wiki labels a pin as ADC but the silicon vendor does not expose an AIN/ADC channel on that chip pin, V1 treats it as digital only.

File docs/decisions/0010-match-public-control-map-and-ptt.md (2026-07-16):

# ADR-0010: Match the observable control map and retain push-to-talk

Status: accepted for V1 fit-check; keycap finish and spacing refined by ADR-0011
Date: 2026-07-16

## Decision

Use twelve MX hot-swap key positions and twelve addressable RGB LEDs. Arrange the visible controls as an encoder, two 1u keys, and a round five-way navigation control on the top row; two rows of four 1u keys; then a circular touch control, one 2u push-to-talk key (`K11`), and one 1u auxiliary key (`K12`) on the bottom row.

The encoder click and navigation-center click remain separate inputs, so removing the extra top-row MX position does not remove either click action. This is an independent implementation of an observable exterior control map. It does not claim or copy unpublished Codex Micro circuitry, dimensions, switch construction, firmware, or protocol.

## Evidence and drivers

- Public Codex Micro product imagery reproduced by The Verge visibly shows two keycaps between the upper-left encoder and upper-right round control, not three.
- The same imagery shows a wide microphone-labelled key immediately right of the circular touch control.
- Axios independently reports push-to-talk as a configurable key function.
- Preserving the earlier thirteen-key count placed an extra MX key where the round navigation control belongs and produced the wrong user-facing layout.

## Constraints

- V1 has no onboard microphone. `K11` controls a host-side audio path through the bridge.
- All twelve key switches use the same bottom-mounted Kailh hot-swap socket candidate, including the single switch under the 2u keycap.
- The exact 2u keycap and stabilizer are not selected. Stabilizer holes and plate cutouts must come from the selected manufacturer's drawing and remain a fabrication blocker.
- The navigation footprint remains an electrical placeholder until the selected part's official land pattern is transcribed and checked.
- Transport loss, heartbeat expiry, reset, bridge restart, or maximum-hold timeout must end capture even if the PTT release event is lost.

## Rejected alternatives

- Keep thirteen MX keys by retaining three top-row keycaps: conflicts with the observable encoder–two-key–navigation grouping.
- Hide the thirteenth key elsewhere: adds a control unsupported by the intended exterior map and complicates the square layout.
- Keep a 1u PTT key with only a software mapping: preserves function but weakens the prominent hold-to-talk affordance.
- Add an onboard microphone: expands power, privacy, acoustic, USB/BLE audio, and enclosure scope beyond the requested controller.

## Consequences

- The key matrix uses twelve of sixteen positions; `K11` remains `ROW3/COL1` and `K12` uses `ROW3/COL3`.
- The serial RGB chain ends at `LED12`; the common MCU interface and `RGB_DATA` GPIO requirement do not change.
- The PCB, switch plate, enclosure renders, protocol documentation, firmware contract, bridge policy, and tests share the same twelve-key control map.
- GPIO pressure decreases slightly; no extra MCU GPIO is required because the MCP23017 still scans the key matrix and navigation contacts.
- The fit-check plate retains only the centered MX opening beneath `K11` until the stabilizer is selected; it is not a fabrication release.

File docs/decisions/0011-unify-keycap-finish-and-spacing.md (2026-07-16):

# ADR-0011: Unify the keycap finish and spacing

Status: accepted for V1 fit-check
Date: 2026-07-16

## Decision

Render all twelve keycaps with one blank black-smoke translucent material and remove the microphone pictogram from K11. Keep K11's `push_to_talk` meaning in bridge configuration and documentation rather than encoding it as permanent keycap artwork.

Place all keycap centers on a 19.0 mm lattice. Use 17.2 mm for the 1u render envelope and 36.2 mm for the 2u render envelope, producing a nominal 1.8 mm key-to-key gap in both axes. Center K11 at the midpoint of its two grid units and move the bottom row onto the same 19 mm vertical pitch as the other rows.

## Drivers

- One finish makes the control surface read as a coherent status instrument while still allowing the per-key RGB to show through.
- Blank caps avoid locking configurable agent actions to permanent artwork.
- The previous bottom row used a 24 mm vertical pitch, and K11 was offset 0.5 mm from the two-unit grid center, producing visibly uneven gaps.
- A single lattice makes PCB, plate, keycap, and enclosure collision checks easier to audit.

## Constraints

- Black-smoke translucency is a visual and optical intent, not a qualified resin, keycap process, or transmission percentage.
- Exact keycap wall thickness, diffuser behavior, RGB brightness, legends, and supplier parts require physical samples.
- K11 remains one centered MX switch under a 2u keycap; stabilizer geometry remains blocked on the selected manufacturer's drawing.
- The circular touch surface occupies the first bottom-row unit but is not treated as a keycap when calculating the 1.8 mm key-to-key gap.

## Consequences

- Mechanical-local bottom-row centers become touch `(28, 24)`, K11 `(56.5, 24)`, and K12 `(85, 24)`.
- KiCad top-side centers become touch `(38, 104)`, K11 `(66.5, 104)`, and K12 `(95, 104)`.
- The touch-to-K11 center pitch becomes 28.5 mm; the nominal touch-recess-to-MX-cutout ligament is 12.4 mm.
- Firmware, protocol, matrix assignments, LED indices, and the K11 default action do not change.

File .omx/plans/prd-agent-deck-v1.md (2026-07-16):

# Agent Deck V1 product requirements and delivery plan

Status: planning baseline  
Date: 2026-07-16  
Owner: repository maintainers

## Outcome

Build and evaluate a PCB-mounted physical AI-agent controller that can control Codex, Hermes, OMX, and tmux sessions through USB or BLE and display normalized agent state using individually addressable RGB lighting on all 12 MX keys. V1 must compare XIAO ESP32-S3 Plus and XIAO nRF52840 Plus without treating the boards as pin-compatible.

## Success criteria

V1 is complete when one common input PCB can be operated through either MCU-specific adapter, all required inputs and RGB outputs pass the bench tests, USB and BLE paths exchange the same semantic protocol, dangerous actions are guarded by host state, and measured evidence is sufficient to select one MCU for the next revision.

## Requirements summary

### Product experience

- Twelve mechanical MX keys, each capable of independent RGB status indication, plus encoder click and navigation center inputs.
- One detented rotary encoder with push switch.
- One five-direction digital navigation switch.
- One circular capacitive touch area supporting tap, long press, and double tap in firmware.
- No OLED or LCD.
- Inputs and LEDs mounted directly to the main input PCB and mechanically supported by the plate or enclosure.
- Physical controls for session selection, new task, approve, reject, interrupt, run tests, open diff, reasoning level, and push-to-talk.
- K11, immediately right of the circular touch control, uses a 2u keycap and defaults to hold-to-talk while remaining one hot-swap MX matrix position and one RGB channel.
- Destructive actions require long press, double confirmation, or another explicit state-aware guard.

### Hardware

- Approximately 1.5 mm switch plate above a 1.6 mm input PCB; final thicknesses depend on the selected switch family and socket geometry.
- Hot-swap sockets and one diode per key.
- Replaceable XIAO ESP32-S3 Plus and XIAO nRF52840 Plus through separate adapter boards.
- USB-first bring-up, followed by protected single-cell Li-Po evaluation.
- Twelve addressable RGB LEDs with level translation, local decoupling, bulk capacitance, aggregate firmware brightness limiting, and a bounded power rail.
- External capacitive-touch controller for a common circuit across both MCUs.
- No duplicate charger on the common input PCB while using XIAO onboard charging.

### Firmware and host

- USB HID keyboard support where practical.
- USB Vendor HID for bidirectional messages; CDC is optional diagnostics only.
- BLE HID plus a custom GATT service on nRF52840; ESP32-S3 may also evaluate BLE and Wi-Fi WebSocket transports.
- A shared logical input/event/state layer with platform adapters for ESP-IDF and Zephyr/nRF Connect SDK.
- A PC bridge that normalizes `idle`, `running`, `waiting_approval`, `waiting_input`, `completed`, and `failed` states.
- Transport-independent message semantics with versioning, sequence numbers, acknowledgements for commands, and explicit capability discovery.

## V1 architecture decision

Use a common input PCB plus two MCU-specific adapter boards.

The direct XIAO socket alternative is rejected for V1 because the similarly positioned D pins do not guarantee identical ADC, NFC, JTAG, battery, USB, boot, or power behavior. An adapter boundary keeps the input PCB stable, gives each board a dedicated battery and USB treatment, and makes later MCU replacement possible without rerouting every input.

See:

- `docs/architecture/system-architecture.md`
- `docs/hardware/pin-compatibility.md`
- `docs/decisions/0001-common-input-pcb-and-mcu-adapters.md`

## Proposed electrical partition

- MCP23017 at 3.3 V scans the 4×4 key matrix and reads the five navigation contacts plus the capacitive-touch output.
- Encoder A, B, and click connect directly to the MCU adapter.
- AT42QT1010-class controller converts the circular copper electrode to a digital touch signal.
- Twelve SK6812 Mini-E-compatible LEDs use one 5 V limited rail, one serial data GPIO through a 74AHCT1G125-class buffer, a 330 ohm first-LED series resistor, 100 nF per LED, and input bulk capacitance.
- Common adapter signals use semantic names: `I2C_SDA`, `I2C_SCL`, `IOX_INT`, `ENC_A`, `ENC_B`, `ENC_SW`, `RGB_DATA`, `RGB_PWR_EN`, optional UART, `3V3`, `VBUS_5V`, and ground.
- V1 exposes the selected XIAO board's onboard USB-C connector. External USB-C routing is deferred until both boards' USB pads and ESD/impedance requirements are separately reviewed.

## Open decisions before schematic freeze

- MX versus Choc switch family, stabilizer needs, socket footprint, key pitch, and keycap profile.
- Exact five-way navigation switch MPN and force/travel.
- Exact encoder MPN, shaft length, detent count, and mounting height.
- Touch electrode diameter, overlay material, thickness, and sensitivity capacitor.
- RGB package/footprint, optical path, maximum firmware brightness, and battery behavior.
- Adapter connector family, pin count, mating height, retention, and current rating.
- Battery capacity, connector, protection, placement, current target, and whether battery-mode RGB needs a boost rail.
- Host platform support order and PC bridge implementation language.
- BLE bonding policy, USB report IDs, and Wi-Fi provisioning scope.

The complete checklist is `docs/hardware/design-inputs-checklist.md`.

## Delivery stages

### 1. Firmware and transport spikes

- Build minimal input, RGB, USB HID, Vendor HID, BLE HID, custom GATT, and reconnect experiments on each development board.
- Confirm the proposed common pin set against real boards, including boot, reset, deep sleep, battery read, and USB enumeration.
- Record current consumption with radios and LEDs in representative states.

Exit: both boards can exchange a protocol ping and one input/state round trip through at least USB, and the nRF52840 can do the same through BLE.

### 2. Schematic

- Select exact switch, encoder, navigation, touch, RGB, connector, protection, and power components.
- Create hierarchical schematics for input matrix, controls, RGB/power, common connector, and each adapter.
- Complete ERC and peer review against manufacturer schematics and data sheets.

Exit: zero unexplained ERC errors and every connector signal has a documented owner, voltage, direction, reset state, and adapter mapping.

### 3. PCB

- Place all user inputs and RGB devices on the common 1.6 mm PCB.
- Route two small adapter PCBs while protecting RF keep-outs, USB access, and battery routing.
- Run DRC, inspect return paths and current loops, and export fabrication files only after 3D interference review.

Exit: zero unexplained DRC errors and signed-off fabrication/assembly outputs for all three boards.

### 4. Plate

- Generate the plate from locked PCB coordinates.
- Ensure switch retention, encoder/joystick support, and acceptable keycap clearances.
- Produce a low-cost test plate before final material selection.

Exit: all controls actuate without plate binding and repeated actuation load is not carried only by solder pads.

### 5. Enclosure

- Provide USB-C, reset/boot access, antenna keep-out, battery retention, and service access.
- Validate the case with board and component 3D models.

Exit: the assembled stack closes without interference and cables can be inserted without stressing the adapter.

### 6. Assembly

- Inspect bare boards, verify shorts and rails, populate power sections first, then logic, LEDs, sockets, controls, and adapters.
- Use current-limited bench power for first power-on.

Exit: all rails and quiescent currents are within the calculated envelope before either XIAO is inserted.

### 7. Integrated test

- Execute `.omx/plans/test-spec-agent-deck-v1.md` for both MCUs.
- Record results in a revisioned test report, including failures and measurement setup.

Exit: sufficient passing evidence and known defects to make an MCU selection decision.

### 8. MCU selection

Score both variants on BLE reconnect, USB behavior, battery life estimate, firmware complexity, host status transport, thermal/current behavior, and failure recovery.

Exit: an ADR selects the V2 MCU or explicitly authorizes another measurement round.

## Acceptance criteria

- Exactly 12 key positions enumerate uniquely and no matrix ghost is observed in the defined multi-key test set.
- All 12 RGB positions can be addressed independently; a firmware current budget prevents unrestricted full-white output.
- Encoder direction, detents, and click are reported without observable edge loss in the specified manual and automated tests.
- All five navigation directions are distinguishable; unsupported simultaneous directions are rejected deterministically.
- Touch tap, long press, and double tap are recognized using documented timing thresholds; swipe is not claimed with a single electrode.
- The same logical message types operate over USB Vendor HID and BLE GATT without host business logic depending on the physical transport.
- USB HID and BLE HID never produce an unguarded destructive action from a single ambiguous input.
- Both adapters survive boot, reset, reconnect, and 30-minute active operation without rail faults or unexplained resets.
- Battery measurements record active, idle, radio-connected, and LED state current; no battery-life claim is made without those measurements.
- KiCad ERC/DRC and the applicable test-spec checks pass or have reviewed, documented waivers.
- Repository documentation contains no assertion about unpublished OpenAI Micro internals.

## Risks and mitigations

- Pin-map similarity hides board-specific functions. Mitigation: semantic adapter connector, reserved D16, official schematic review, and hardware spikes.
- Addressable LED current dominates battery life. Mitigation: switched rail, hardware current limit, global firmware current budget, and event-driven lighting.
- I2C scanning adds key latency or sleep complexity. Mitigation: 400 kHz evaluation, direct encoder wiring, interrupt-assisted slow controls, and an explicit remove-MCP option for V2.
- Touch sensitivity shifts with enclosure material and grounding. Mitigation: test coupons, adjustable sensitivity component, guard/keep-out study, and final overlay testing.
- USB and battery power paths back-feed. Mitigation: keep charging on adapters, review both XIAO schematics, and test every insertion/power combination with current limiting.
- Host integrations rely on unstable CLI output. Mitigation: adapter-based parsers, capability/version checks, fixtures, and graceful `unknown` state.
- Dangerous actions are mapped too directly. Mitigation: semantic action intents, session/state validation, acknowledgement, and explicit confirmation policy.

## Verification

The primary proof is the measured test matrix in `.omx/plans/test-spec-agent-deck-v1.md`. Document review alone cannot approve pin compatibility, RF performance, USB behavior, battery life, or touch sensitivity.

## Stop condition

Planning is complete when this PRD, the test specification, the pin compatibility note, architecture, BOM draft, protocol, and design-input checklist agree. Implementation begins only after the first-stage firmware/transport spike has named owners and exact board revisions.

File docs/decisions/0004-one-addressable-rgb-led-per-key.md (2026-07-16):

# ADR-0004: Fit one addressable RGB LED to every mechanical key

Status: superseded in count by ADR-0010; per-key RGB remains accepted
Date: 2026-07-16

## Decision

Increase the common input PCB from six to thirteen SK6812 Mini-E-compatible LEDs so every mechanical key has independent status lighting. Keep the existing one-wire `RGB_DATA` chain, default-off `RGB_PWR_EN`, 5 V level shifter, current-limited load switch, local 100 nF capacitor per LED, and provisional 120 mA aggregate firmware budget.

## Drivers

- Per-key lighting can show session selection, input layers, pending actions, and safety confirmation without adding a display.
- Addressable LEDs add no MCU GPIO as the chain grows; both MCU adapters keep the same semantic connector.
- Fitting the optional positions now avoids a later PCB spin solely for lighting.

## Constraints

- Thirteen requested full-white pixels cannot be assumed safe or useful at unrestricted brightness.
- Firmware must apply a frame-wide brightness/current clamp; the TPS2553 remains the hardware backstop rather than the normal regulator of animation brightness.
- Added switching current and data routing must not compromise the adjacent capacitive-touch electrode.
- Exact LED land pattern, reverse-mount cutout, keycap optical stack, and current-limit resistor remain fabrication blockers.

## Rejected alternatives

- Six illuminated keys only: limits semantic feedback and makes the unlit keys mechanically inconsistent.
- Discrete non-addressable RGB LEDs: would require a dedicated matrix/driver and more routing without a V1 benefit.
- Raise the hardware limit immediately: rejected until optical brightness, USB budget, transient, and thermal measurements exist.

## Consequences

- The common PCB carries LED1 through LED13 and thirteen local decoupling capacitors.
- Protocol capabilities and firmware mapping expose 13 physical LED indices.
- Power tests include an all-LED requested-white case and verify the aggregate software clamp.
- GPIO allocation and both MCU adapter boards remain unchanged.

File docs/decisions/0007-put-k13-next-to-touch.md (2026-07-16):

# ADR-0007: Put K13 immediately beside the touch control

Status: superseded in part by ADR-0010
Date: 2026-07-16

## Decision

Move K13 from the provisional lower-right position to the position immediately right of the circular touch control. Use a 22 mm touch-to-key center pitch, reduce the case touch recess from 22 mm to 18 mm, and map K13 to matrix position `ROW3/COL1`.

This is an independent layout decision for the intended user experience. Public exterior references may inform the control grouping, but no unpublished OpenAI Micro dimensions, circuitry, or protocol are assumed or copied.

## Drivers

- The previous lower-right K13 coordinate left an unintended blank control position beside the touch surface.
- A 22 mm center pitch preserves the intended grouping while keeping the bottom-mounted socket lands outside the 11.5 mm touch quiet zone.
- An 18 mm recess leaves a nominal 5.9 mm plate ligament to the 14.2 mm MX opening and a 4.4 mm visible gap to the 17.2 mm keycap proxy.

## Constraints

- The PCB touch electrode remains the current 14 mm candidate; only the enclosure recess changes.
- Touch sensitivity through the 0.8 mm membrane and the effect of the adjacent switch, LED, ground, and hand position require physical coupon testing.
- K13's diode, LED, decoupling capacitor, data trace, and matrix mapping must move together.
- C30 moves away from K13's new footprint but remains on the same LED supply rail.

## Rejected alternatives

- Keep K13 at the lower right: preserves an accidental gap and weakens the intended touch-plus-key control cluster.
- Preserve the grid's 19 mm pitch: leaves insufficient margin between the touch quiet zone and the hot-swap socket copper.
- Guess a product-specific pitch from exterior imagery: public images are insufficient mechanical evidence.

## Consequences

- The PCB, LED chain, switch plate, enclosure renders, and firmware matrix map use one consistent K13 location.
- The lower-right case area becomes available for the navigation/adapter region rather than an isolated key.
- Fabrication remains blocked until touch and plate coupons confirm the nominal ligament and sensing margin.

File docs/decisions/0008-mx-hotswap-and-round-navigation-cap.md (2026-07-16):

# ADR-0008: Use MX hot-swap keys and a low round navigation cap

Status: superseded in count and placement by ADR-0010; part-family decision remains accepted
Date: 2026-07-16

## Decision

Lock the V1 key family to 5-pin MX-compatible mechanical switches, use one bottom-mounted Kailh `CPG151101S11-16` hot-swap socket per key, and reduce the printable switch plate to 1.5 mm nominal thickness. Keep the exact MX switch force/sound MPN open until samples are tested.

Use ALPS Alpine `RKJXM1015004` as the current through-hole navigation-switch candidate and model a separate 14 mm low round concave cap. The cap follows the desired public exterior language; the internal part and dimensions remain an independent candidate, not a claim about OpenAI Micro internals.

## Drivers

- Switch replacement should not require desoldering.
- A plate-mounted MX stack supports repeated switch insertion and normal key actuation better than sockets alone.
- The newer Kailh socket drawing specifies a 1.85 mm body below the PCB, which fits the current tray with 1.25 mm nominal floor clearance.
- The public exterior reference uses a low round thumb control rather than a square navigation button.
- The RKJXM candidate provides through-hole retention, center push, and separate cardinal contacts while staying close to the intended cap envelope.

## Constraints

- The socket is not compatible with Choc switches; no universal overlapping footprint is permitted in V1.
- K13 uses the same socket orientation as the other keys; its 22 mm center pitch keeps socket copper outside the adjacent touch quiet zone.
- The exact switch, keycap, socket revision, paste aperture, plate latch tolerance, and insertion force require physical samples.
- The RKJXM land pattern remains an explicit electrical placeholder until every official terminal and support hole is transcribed and independently checked.
- Diagonal stick motion is represented as simultaneous cardinal contacts and must be handled deterministically in firmware.

## Rejected alternatives

- Solder switches directly: makes switch-force comparison and replacement unnecessarily destructive.
- Universal MX/Choc footprint: increases mechanical and routing risk without a selected Choc product requirement.
- Square five-way cap: meets electrical needs but misses the requested low round thumb-control experience.
- Assume the public reference's internal joystick part: exterior images do not disclose the internal component.

## Consequences

- The PCB generator now owns a centered MX/Kailh socket footprint, so PCB and case key centers share one datum.
- All 13 keys are mechanically replaceable after the socket and plate pass sample validation.
- The enclosure renderer and dimensions expose the round navigation cap, socket height, and floor clearance.
- Fabrication remains blocked by the open land-pattern, sample-fit, and DRC gates.

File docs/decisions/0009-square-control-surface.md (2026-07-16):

# ADR-0009: Use a square V1 control surface

Status: superseded in control placement by ADR-0010; square envelope remains accepted
Date: 2026-07-16

## Decision

Change the common input PCB from a 132 mm × 92 mm rectangle to an independent 118 mm × 118 mm square datum. Use a matching 118.8 mm square control plate and a 125.8 mm × 125.8 mm enclosure body. Rebalance the keys and right-side controls inside the new datum while preserving all thirteen MX hot-swap keys, thirteen RGB LEDs, the touch-plus-K13 grouping, encoder, and round navigation cap.

The square silhouette is a user-experience choice informed by public product imagery. It is not a claim about unpublished Codex Micro dimensions, PCB geometry, component placement, or internal construction.

## Drivers

- The requested visual language is a compact square controller rather than a wide macro pad.
- A square PCB, plate, and case keep the mechanical coordinate contract honest; a square cosmetic shell around the previous rectangular PCB would waste internal volume and hide the actual layout constraint.
- The added rear quadrant gives the MCU connector and logic/power parts a distinct region away from repeated control loads.

## Constraints

- The V1 square side length is a prototype choice, not a dimension inferred from photographs.
- Control centers, mounting holes, copper zones, case bosses, plate openings, and render proxies must move together.
- The XIAO USB service opening remains provisional until the adapter connector height and board orientation are physically frozen.
- The navigation land pattern, touch overlay, battery volume, and first-article fit remain fabrication blockers.

## Rejected alternatives

- Square enclosure around the existing 132 mm × 92 mm PCB: produces a square exterior but preserves an unnecessarily wide internal architecture.
- Scale every coordinate uniformly: changes the standard 19 mm MX pitch and invalidates the selected switch/keycap stack.
- Copy dimensions from exterior imagery: photographs do not provide reliable manufacturing dimensions.

## Consequences

- The common PCB and printable fit-check now share a 118 mm square source envelope.
- The enclosure body is 125.8 mm square and remains 17.0 mm high before controls.
- Firmware matrix mapping and the shared device protocol do not change.
- Existing rectangular STL files are superseded by regenerated square fit-check exports with the same filenames.

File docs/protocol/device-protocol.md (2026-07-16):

# Agent Deck device protocol v1 draft

## Goals

- Carry the same semantic messages over USB Vendor HID, BLE GATT, and optional Wi-Fi WebSocket.
- Keep USB reports bounded to 64 bytes.
- Recover cleanly from disconnects and process restarts.
- Prevent duplicated or stale sensitive actions.
- Allow firmware and bridge versions to negotiate capabilities.

USB HID keyboard reports are separate from this control protocol. CDC logs are diagnostics only.

## Envelope

The transport-independent v1 envelope is 8 bytes plus up to 56 payload bytes:

| Byte | Field | Meaning |
| --- | --- | --- |
| 0 | `major` | Breaking protocol version; v1 is `1` |
| 1 | `type` | Message type ID |
| 2 | `flags` | `ACK_REQUIRED`, `RESPONSE`, `ERROR`, reserved bits |
| 3 | `length` | Payload length, 0–56 |
| 4–5 | `sequence` | Little-endian sender sequence, wraps modulo 65536 |
| 6–7 | `request_id` | Correlates commands and results; zero for unsolicited state |
| 8–63 | `payload` | Message-specific fixed fields or compact TLV fields |

USB uses fixed 64-byte reports with zero padding. BLE uses the exact `8 + length` bytes in GATT characteristics. WebSocket uses one binary message per envelope. Transport security and integrity are not replaced by this header.

## Lifecycle

1. Transport connects.
2. Each side sends `HELLO` with implementation ID, protocol minor, capability bits, maximum payload, and a random connection epoch.
3. The bridge sends a complete `STATE_SNAPSHOT`.
4. Both sides exchange `HEARTBEAT` while idle.
5. Disconnect or heartbeat expiry cancels pending confirmations and action requests.

Sequence numbers are checked within one connection epoch. A new epoch invalidates all pending request IDs.

## Message types

| ID | Name | Direction | Purpose |
| --- | --- | --- | --- |
| `0x01` | `HELLO` | Both | Version, capabilities, connection epoch |
| `0x02` | `HELLO_ACK` | Both | Negotiated features or rejection reason |
| `0x03` | `HEARTBEAT` | Both | Liveness and monotonic uptime |
| `0x04` | `ACK` | Both | Generic receipt/reject status |
| `0x10` | `STATE_SNAPSHOT` | PC → device | Complete current device-visible state |
| `0x11` | `SET_AGENT_STATE` | PC → device | Update one agent/session state |
| `0x12` | `SET_SELECTED_AGENT` | PC → device | Selected stable session ID |
| `0x13` | `SET_LED` | PC → device | Explicit LED override with expiry |
| `0x14` | `SET_BRIGHTNESS` | PC → device | Global brightness/current policy |
| `0x15` | `SET_MODE` | PC → device | Named interaction/display mode |
| `0x16` | `ACTION_RESULT` | PC → device | Result of a semantic action request |
| `0x17` | `SET_BATTERY_DISPLAY_MODE` | PC → device | Battery indication policy |
| `0x20` | `KEY_EVENT` | Device → PC | Key ID, press/release, duration, modifiers |
| `0x21` | `ENCODER_DELTA` | Device → PC | Signed delta and acceleration class |
| `0x22` | `ENCODER_CLICK` | Device → PC | Press/release and duration |
| `0x23` | `JOYSTICK_EVENT` | Device → PC | Direction/center press/release |
| `0x24` | `TOUCH_EVENT` | Device → PC | Tap, double tap, long press, raw press/release |
| `0x25` | `DEVICE_STATUS` | Device → PC | Firmware, adapter, transport, fault flags |
| `0x26` | `BATTERY_LEVEL` | Device → PC | Millivolts, percent estimate, charge flags |
| `0x27` | `ACTION_INTENT` | Device → PC | Guarded semantic action for a stable session |

## Stable identifiers and state versions

The bridge assigns a 32-bit `session_id` valid for its current runtime epoch and a monotonically increasing 32-bit `state_version`. Device display updates carry both. Sensitive `ACTION_INTENT` payloads include:

- bridge connection epoch
- selected `session_id`
- last displayed `state_version`
- action code
- gesture class (`short`, `long`, `double`, `chord`)
- measured hold duration where applicable

The bridge rejects the intent if the epoch, session, or state version is stale. A visual selection alone is not authorization.

## Normalized states

| Code | Name | Default display meaning |
| --- | --- | --- |
| 0 | `idle` | Available, no active work |
| 1 | `running` | Work in progress |
| 2 | `waiting_approval` | Explicit approval decision required |
| 3 | `waiting_input` | User content/input required |
| 4 | `completed` | Last work completed |
| 5 | `failed` | Work failed or integration error |
| 6 | `disconnected` | Bridge heartbeat lost; device-local state |

Color values are configurable. State codes are stable protocol semantics; specific colors are not.

## Default control binding and push-to-talk lifecycle

K11 is the V1 default `push_to_talk` control. This is a bridge configuration default, not a hard-coded protocol key meaning: `KEY_EVENT` continues to carry stable physical key ID, press/release state, and duration so the control can be remapped.

- K11 press starts host-side audio capture only after the active integration reports voice input support.
- K11 release stops capture. Firmware must emit release; the bridge must not infer a fixed recording duration.
- Transport loss, heartbeat expiry, device reset, bridge restart, or the configured maximum hold timeout stops capture even if a release event is lost.
- The device contains no microphone in V1. Audio stays on the host audio path.
- Push-to-talk is not sent as raw Enter or an arbitrary global keyboard shortcut.

## Sensitive action policy

- `approve`, `reject`, `interrupt`, `push`, `deploy`, and `delete` are sent as `ACTION_INTENT`, never as raw Enter.
- The bridge owns the required session state and confirmation rule.
- Every accepted intent produces one terminal `ACTION_RESULT` or times out visibly.
- Duplicate `request_id` in the same epoch returns the previous result without executing twice.
- A reconnect never replays a pending sensitive action.

## Capability examples

- USB keyboard HID
- USB Vendor HID
- BLE HID
- custom BLE GATT
- Wi-Fi WebSocket
- battery measurement
- 12 independently addressable RGB key LEDs
- touch gestures
- firmware update mechanism

Capability bits are additive within a major protocol version. Unknown bits are ignored; missing required capabilities cause a clear negotiation failure.

## Golden-vector requirement

Before either implementation is considered compatible, firmware and bridge tests must share byte-for-byte golden vectors for every message, boundary length, malformed packet, duplicate sequence, stale epoch, and unknown enum case.

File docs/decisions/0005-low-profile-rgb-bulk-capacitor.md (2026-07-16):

# ADR-0005: Replace the tall radial RGB reservoir with a low-profile SMD candidate

Status: accepted for V1 engineering draft  
Date: 2026-07-16

## Decision

Replace the provisional 470 uF, 8 mm × 11.5 mm radial capacitor with Panasonic `10TPF150ML` as the V1 low-profile RGB bulk candidate. Keep the aggregate RGB budget near 120 mA, add a 10 uF X7R local LED-rail capacitor, and add a separate 10 uF X7R local 3.3 V capacitor.

## Drivers

- The radial component protruded above the planned PCB-to-plate clearance and forced unnecessary enclosure height.
- Panasonic's official model table lists `10TPF150ML` as 150 uF, 10 V, and 7.3 mm × 4.3 mm × 2.8 mm.
- The hardware current limiter and firmware frame clamp reduce the need to assume a 470 uF reservoir before transient measurements exist.

## Constraints

- The selected capacitor is polarized; polarity must be visible in the schematic, footprint, assembly drawing, and inspection checklist.
- The draft EIA-7343-31 footprint is not asserted to be Panasonic's approved land pattern.
- Capacitance, ESR, inrush, USB droop, and all-LED switching remain bench-test requirements.

## Rejected alternatives

- Keep the radial 470 uF part: avoidable 11.5 mm height and poor enclosure fit.
- Remove the bulk capacitor entirely: transient behavior has not been measured.
- Increase the enclosure height around C30: solves the symptom while preserving an unverified electrical assumption.

## Consequences

- The PCB control-side height target for C30 drops from 11.5 mm to approximately 2.8 mm for the candidate body.
- The enclosure fit-check can keep a sub-5 mm PCB-to-plate component gap at C30.
- Fabrication remains blocked until the exact Panasonic drawing, land pattern, sourcing, and transient behavior are reviewed.

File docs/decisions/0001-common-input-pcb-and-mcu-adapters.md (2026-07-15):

# ADR-0001: Common input PCB with MCU-specific adapters

Status: accepted for V1 planning  
Date: 2026-07-16

## Decision

Build one common input PCB and two small adapter boards, one for XIAO ESP32-S3 Plus and one for XIAO nRF52840 Plus. The common connector carries semantic signals and power domains rather than raw XIAO D0–D19 positions.

## Drivers

- Compare both MCUs without respinning every user input.
- Contain board-specific USB, battery, reset/boot, NFC, JTAG, and RF constraints.
- Make electrical differences visible and reviewable.
- Retain a path to another MCU without discarding the mechanical input assembly.

## Alternatives considered

### Direct XIAO Plus socket on the common PCB

Lower part count and height, but it encourages false pin-compatibility assumptions and makes board-specific power/USB routing difficult to isolate.

### Two complete input PCBs

Maximum freedom for each MCU, but duplicates the largest mechanical PCB and weakens the fairness of comparative testing.

## Consequences

- The enclosure must reserve adapter volume and support the XIAO USB connector.
- Adapter connector height and retention become early mechanical decisions.
- Three PCB designs are fabricated, but only the small adapters vary by MCU.
- Pin changes are localized to adapter schematics and firmware board definitions.

## Follow-ups

- Select the adapter connector and mating height.
- Prototype USB access and antenna clearance.
- Add adapter identity and prevent wrong-firmware assumptions.
- Revisit after V1 selects the final MCU; V2 may integrate that MCU directly.

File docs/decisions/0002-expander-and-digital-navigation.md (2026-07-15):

# ADR-0002: MCP23017 and digital navigation contacts for V1

Status: accepted for V1 planning  
Date: 2026-07-16

## Decision

Use MCP23017 on the common PCB for the 4×4 key matrix, five navigation contacts, and touch-controller output. Keep encoder A/B/click directly connected to the MCU. Do not use an ADC resistor ladder for the V1 navigation switch.

## Drivers

- Reduce the common MCU interface to a small conservative pin subset.
- Avoid cross-MCU ADC thresholds and calibration for navigation input.
- Keep timing-sensitive quadrature edges off I2C.
- Make each navigation direction easy to test and diagnose.

## Alternatives considered

- Directly connect all inputs to MCU GPIO: lower BOM but consumes most candidate pins and couples the main board to MCU-specific details.
- ADC resistor ladder: uses one pin but adds voltage tolerances, simultaneous-press ambiguity, and per-MCU calibration.
- Individual key wiring on MCP23017: simple scanning but leaves insufficient pins for all navigation contacts.

## Consequences

- Firmware needs a shared MCP23017 driver and matrix scanner.
- I2C latency, wake behavior, and sleep current must be measured.
- Two expander pins remain available for fixtures or future low-speed inputs.
- V2 may remove the expander if measurement supports a simpler direct-GPIO design.

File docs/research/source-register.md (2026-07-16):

# Official source register

Accessed: 2026-07-16

These links are the evidence baseline for board-level claims. Before schematic release, record the revision printed on each purchased board and download the matching official schematic locally for review. Links may move; do not substitute reseller pinout images for the official sources.

## Seeed Studio XIAO ESP32-S3 Plus

- [Official XIAO ESP32-S3 Series wiki](https://wiki.seeedstudio.com/xiao_esp32s3_getting_started/) — Plus D0–D19 map, power pins, strapping caution, boot/reset, battery behavior, and official design resource links.
- [Official XIAO ESP32-S3 Plus schematic PDF](https://files.seeedstudio.com/wiki/SeeedStudio-XIAO-ESP32S3/res/XIAO_ESP32S3_Plus_SCH_PDF.pdf) — board nets, battery/charger, bottom pads, USB, and XIAO headers. Search result identified V1.1 dated 2025-07-24; confirm against the exact downloaded file at design freeze.
- [Official XIAO Plus baseboard KiCad project](https://files.seeedstudio.com/wiki/SeeedStudio-XIAO-ESP32S3/res/XIAO_Plus_Base_with_botton_pad_lead_out_V1.0.zip) — source for the physical Plus land pattern transcribed into the adapter draft. Pad geometry still requires a purchased-board fit check.
- [Espressif ESP32-S3 datasheet](https://documentation.espressif.com/esp32-s3_datasheet_en.pdf) — silicon pin restrictions, ADC channels, USB D+/D-, and strapping pins.
- [Espressif ESP32-S3 hardware design guidelines](https://documentation.espressif.com/projects/esp-hardware-design-guidelines/en/latest/esp32s3/schematic-checklist.html) — boot straps, USB layout, reset and GPIO guidance.
- [ESP-IDF USB Device Stack](https://docs.espressif.com/projects/esp-idf/en/stable/esp32s3/api-reference/peripherals/usb_device.html) — HID, vendor, composite device, endpoint, and native USB constraints.

## Seeed Studio XIAO nRF52840 Plus

- [Official XIAO nRF52840 Series wiki](https://wiki.seeedstudio.com/XIAO_BLE/) — Plus D0–D19 map, interfaces, battery read notes, charger, SWD, and official design resource links.
- [Official XIAO nRF52840 Plus schematic PDF](https://files.seeedstudio.com/wiki/XIAO-BLE/Seeed_Studio_XIAO_nRF52840_Plus_PDF.pdf) — board nets, charger, bottom pads, USB, and XIAO headers. Confirm board and schematic revision before release.
- [Nordic nRF52840 Product Specification](https://docs.nordicsemi.com/r/bundle/ps_nrf52840/) — electrical limits, GPIO, USB, radio, SAADC, power, and NFC.
- [Nordic nRF52840 pin assignments](https://docs.nordicsemi.com/r/bundle/ps_nrf52840/page/pin.html) — authoritative AIN-capable pin names and digital pin restrictions.

## Known documentation cautions

- The Seeed ESP32-S3 Plus wiki labels D11/GPIO38 as ADC, while the Espressif GPIO reference does not list GPIO38 as an ADC channel. V1 treats D11 as digital only.
- The Seeed nRF52840 Plus wiki labels several D11–D15 rows as ADC even though Nordic identifies analog inputs by specific `AIN` pin names. V1 only treats D0–D5 and D16 as analog-capable where the Nordic pin assignment supports it.
- D16 is a battery measurement path on both boards, but the surrounding circuitry and enable behavior are not equivalent.
- A current wiki page may describe a newer board revision than purchased hardware. The silkscreen and exact schematic revision are part of test evidence.

## Component sources to add before schematic freeze

Sources already used by the engineering draft:

- [Microchip MCP23017 data sheet](https://ww1.microchip.com/downloads/aemDocuments/documents/APID/ProductDocuments/DataSheets/MCP23017-Data-Sheet-DS20001952.pdf) — SOIC-28 pin allocation, address/reset, I2C, and interrupt pins.
- [Microchip AT42QT1010 data sheet](https://ww1.microchip.com/downloads/en/DeviceDoc/40001946A.pdf) — SOT-23-6 pinout and the `SNSK`/`SNS`/`Cs` single-electrode reference circuit.
- [TI SN74AHCT1G125 data sheet](https://www.ti.com/lit/gpn/sn74ahct1g125) — AHCT input threshold, active-low output enable, and DBV pinout.
- [TI TPS2552/TPS2553 data sheet](https://www.ti.com/lit/ds/slvs841e/slvs841e.pdf) — DBV pinout, active-high TPS2553 enable, fault output, and `ILIM` equation. The draft uses 232 kΩ as a candidate near 117 mA typical; tolerance and optical tests remain required.
- [Panasonic 10TPF150ML official model page](https://industrial.panasonic.com/ww/products/pt/poscap/models/10TPF150ML) — provisional low-profile RGB bulk capacitor candidate. Panasonic lists 150 uF, 10 V, D3L size, and a 7.3 mm × 4.3 mm × 2.8 mm body; exact land pattern and polarity require drawing review before fabrication.
- [Kailh CPG151101S11-16 official drawing and specification](https://m.kailhswitch.com/uploads/15927/files/CPG151101S11-16.pdf?rnd=10) — MX hot-swap socket profile, bottom-side assembly, recommended PCB layout, 1.85 mm body height, 3 mm switch-pin holes, and 5,000-cycle candidate life. Verify the purchased revision against the drawing.
- [ALPS Alpine RKJXM1015004 official product page](https://tech.alpsalpine.com/e/products/detail/RKJXM1015004/) — 8-direction stick switch with center push, 11 mm × 11 mm × 6.6 mm body, official mounting drawing, output table, and CAD download. The V1 firmware uses cardinal contacts and treats diagonals as simultaneous contacts.
- [Work Louder Creator Micro 2 official product page](https://worklouder.cc/creator-micro-2) — public exterior/function reference for a low round joystick-cap construction. It does not establish the unpublished Codex Micro internal component, circuit, or key count.

## Public Codex Micro experience references

These sources support only observable exterior/function decisions. They are not evidence for the unpublished MCU, circuit, dimensions, firmware, or protocol.

- [The Verge: OpenAI made a $230 keyboard to control Codex](https://www.theverge.com/ai-artificial-intelligence/965901/openai-hardware-codex-micro-launch) — public product imagery shows a wide microphone-labelled key immediately right of the circular touch control; reporting describes push-to-talk as a configurable command-key action.
- [Axios: OpenAI launches a keypad for AI agents](https://www.axios.com/2026/07/15/openai-keyboard-codex-agents) — independently reports customizable keys including a push-to-talk option.

Add official manufacturer data sheets for the selected:

- RGB LED and level shifter
- current-limited load switch
- exact MX mechanical switch and keycap
- encoder
- adapter connector
- ESD/protection parts
- Li-Po cell and connector

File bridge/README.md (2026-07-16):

# PC bridge architecture

The bridge converts unstable tool-specific observations into a stable device model and converts semantic device actions into state-checked tool commands.

## Proposed modules

```text
bridge/
  src/
    core/          # session registry, state normalization, selection
    policy/        # sensitive action authorization and confirmation
    protocol/      # shared envelope and messages
    transports/    # vendor HID, BLE GATT, WebSocket
    integrations/  # codex, hermes, omx, tmux
    config/        # validation, migrations, key mappings
    audit/         # structured guarded-action records
  tests/
    fixtures/
    integration/
    protocol/
```

Implementation language is deliberately not selected until a short spike compares USB HID, BLE, process watching, distribution, and testability on the primary host OS.

## Internal contracts

### Integration adapter

An integration adapter exposes:

- discover sessions
- poll or subscribe to session state
- read stable metadata and capabilities
- execute one semantic action against a stable session identifier
- return structured success, rejection, timeout, or unsupported results

Parsing CLI screen text is an adapter implementation detail and never becomes the device protocol.

### Session registry

The registry merges integration observations into:

- runtime-scoped numeric session ID
- integration kind and upstream identifier
- normalized state and state version
- label suitable for local logs/configuration
- supported semantic actions
- last observation and health

### Policy engine

The policy engine checks connection epoch, selected session, state version, supported action, configured gesture, and optional second confirmation. It records a structured audit event before and after execution.

### Transport adapter

USB Vendor HID, BLE GATT, and WebSocket adapters all emit/consume the envelope in `docs/protocol/device-protocol.md`. Reconnection always triggers capability negotiation and a complete snapshot.

## Configuration

See `config.example.yaml`. Real configuration and credentials stay outside the repository. Mappings refer to semantic actions, not shell snippets, for guarded operations.

## Integration priorities

1. tmux session discovery and selection.
2. A fixture-backed generic agent state source.
3. Codex integration with explicit version/capability detection.
4. OMX and Hermes adapters behind the same interface.
5. Optional Wi-Fi/WebSocket device transport.

## Safety rules

- A single short press cannot directly invoke push, deploy, delete, or approval unless an explicit reviewed policy allows it for a non-sensitive context.
- Shell commands use argument arrays or validated adapters; no device-supplied string is evaluated as a shell command.
- A transport reconnect cannot replay pending actions.
- A stale session or state version is rejected, not silently redirected to the new selection.
- Adapter failure yields `failed` or `unknown` health and does not crash the transport loop.
- K11 defaults to hold-to-talk: press starts host-side capture and release stops it. Disconnect, heartbeat expiry, bridge restart, or a configured maximum hold timeout must also stop capture.
- Push-to-talk is a semantic integration action, not an injected global hotkey. The bridge selects the supported Codex/host voice-input adapter and exposes a visible failure when none is available.

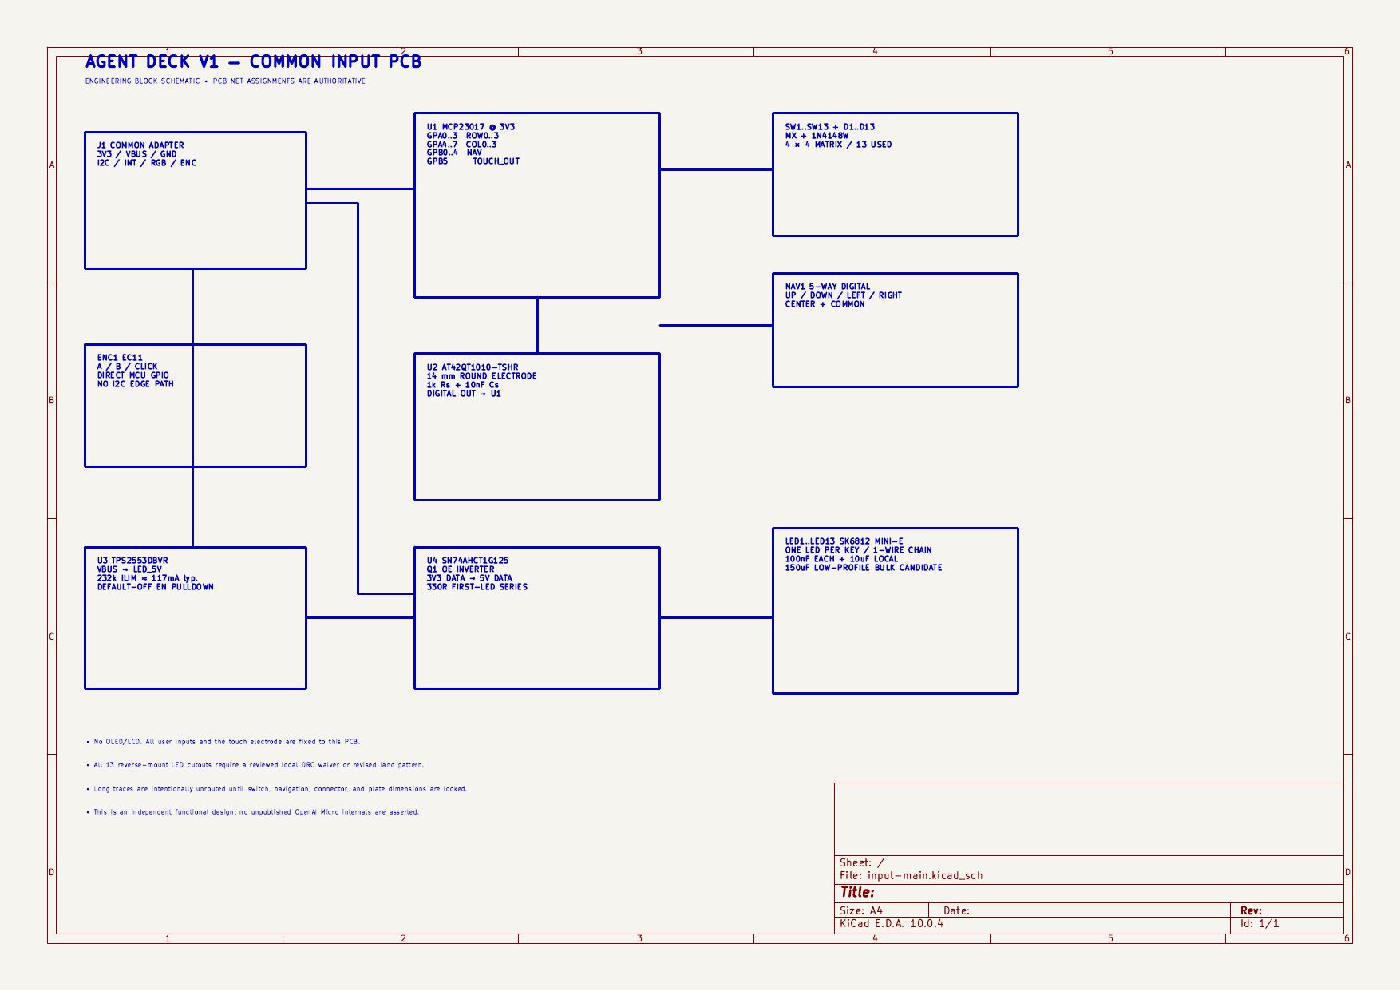
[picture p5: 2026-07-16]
docs/images/pcb/input-main-schematic.png

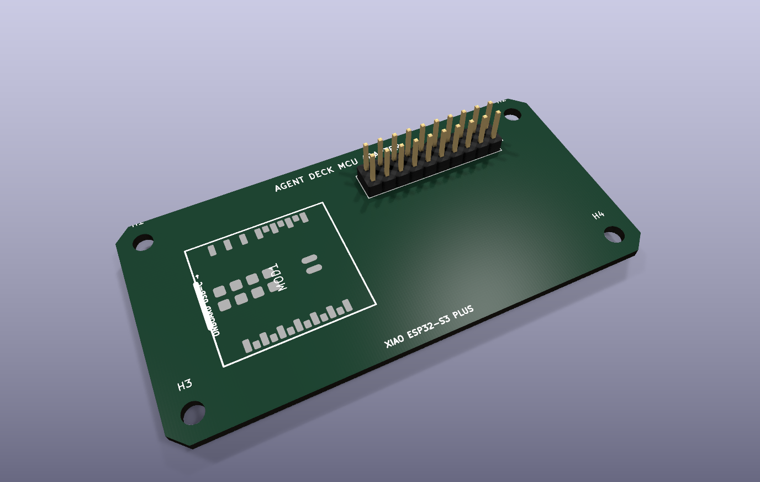
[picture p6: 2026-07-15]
docs/images/pcb/xiao-esp32s3-plus.png

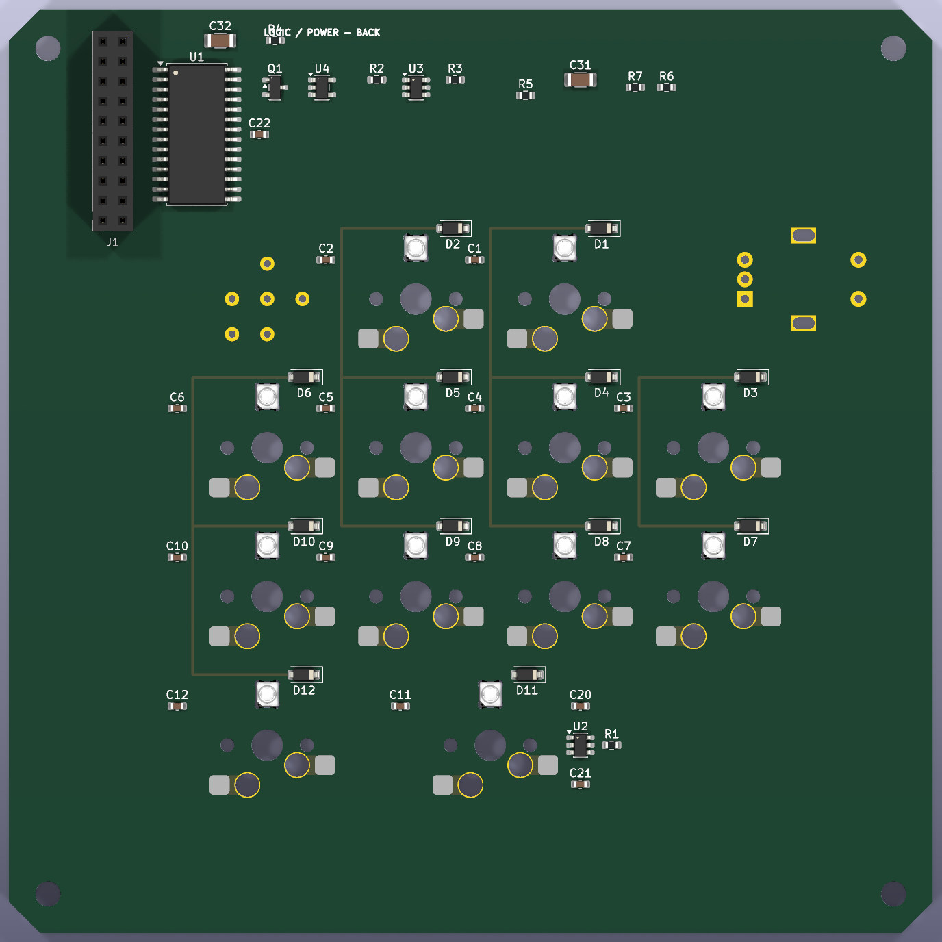
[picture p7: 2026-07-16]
docs/images/pcb/input-main-bottom.png

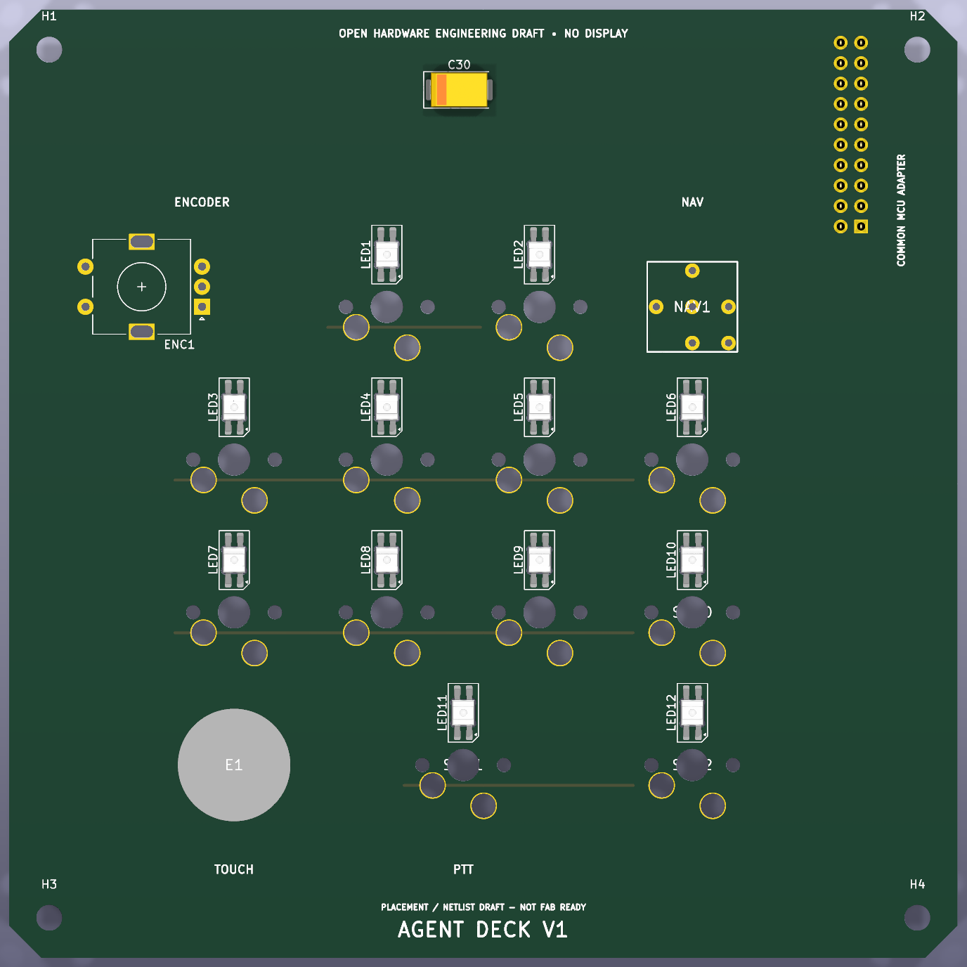
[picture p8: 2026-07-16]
docs/images/pcb/input-main-top.png

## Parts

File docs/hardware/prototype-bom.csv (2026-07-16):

Group | Qty | Function | Preferred candidate / MPN | Alternative | Footprint or selection note | Procurement note
MCU adapter | 1 | Wi-Fi/BLE/USB comparison board | Seeed Studio XIAO ESP32-S3 Plus | None; exact Plus revision required | Socketed on ESP32-S3 adapter | Verify official Korean distributor or DigiKey/Mouser Korea stock before order
MCU adapter | 1 | Low-power BLE/USB comparison board | Seeed Studio XIAO nRF52840 Plus | None; exact Plus revision required | Socketed on nRF52840 adapter | Verify official Korean distributor or DigiKey/Mouser Korea stock before order
Input expander | 1 | Key matrix, navigation, touch input | MCP23017-E/SO | MCP23017T-E/SO | SOIC-28 for prototype hand rework | Commonly stocked by global distributors; recheck lead time
Touch controller | 1 | Single circular capacitive electrode | AT42QT1010-TSHR | CAP1203-1-SN for later multi-electrode study | SOT-23-6 preferred candidate; alternative is not footprint-compatible | Order evaluation quantity plus tuning passives
Addressable RGB | 12 | One independently addressable status LED per key | SK6812MINI-E | WS2812B-2020 or compatible family | Do not treat alternatives as footprint/pin compatible without drawing review | Domestic maker shops often stock modules/loose LEDs; verify genuine data sheet and reel orientation
Logic buffer | 1 | 3.3 V to 5 V RGB data level shift | SN74AHCT1G125DBVR | 74AHCT1G125GW,125 | SOT-23-5/SOT-353 alternatives are not footprint-compatible | Use AHCT input thresholds; do not substitute HC blindly
RGB load switch | 1 | Switched, current-limited LED rail | TPS2553DBVR | AP22653W6-7 | Current-limit equation and package differ | Select only after current target and distributor stock review
RGB current-set resistor | 1 | TPS2553 current-limit candidate | 232 kOhm 1% | 220 kOhm 1% after measured-current review | 0603/0805; candidate is about 117 mA typical from TI equation | Do not treat the typical equation as a guaranteed maximum
RGB enable transistor | 1 | Invert RGB_PWR_EN for active-low AHCT output enable | MMBT3904LT1G | BC847B after pinout/package review | SOT-23; verify B/E/C pad mapping for substitute | Generic SOT-23 transistors are not automatically pin-compatible
RGB enable resistors | 2 | Base drive and output-enable pull-up | 10 kOhm 1% candidate | 4.7-47 kOhm after timing/leakage review | 0603 or 0805 | One base resistor and one VBUS-referenced OE pull-up
Mechanical key | 12 | Primary input switches | TBD: 5-pin MX-compatible exact MPN | 3-pin plate-mount MX after retention review | V1 is MX-only; exact force, sound, height, and keycap remain blocking | Buy clicky and silent sample sets before plate freeze
Hot-swap socket | 12 | Replaceable mechanical switches | Kailh CPG151101S11-16 | Kailh CPG151101S11 only after revision/drawing comparison | Bottom-mounted MX socket; not Choc-compatible | Domestic keyboard shops commonly carry Kailh MX sockets; verify genuine revision and drawing
Key diode | 12 | Matrix isolation | 1N4148W-7-F | Any qualified 1N4148W with matched package/polarity | SOD-123 | Widely available domestically and globally
Rotary encoder | 1 | Rotation plus click | ALPS Alpine EC11E15244G1 candidate | Bourns PEC11R series after dimension match | Exact shaft, pulses, detents, tabs, and height must be locked | Check Eleparts/DeviceMart and global distributor stock
Encoder knob | 1 | User control | TBD after shaft selection | Any dimensionally qualified knob | Match shaft type and enclosure clearance | Buy with encoder samples
Navigation switch | 1 | Up/down/left/right/center with simultaneous-contact diagonals | ALPS Alpine RKJXM1015004 candidate | ALPS SKRVAAE010 plus custom cap after force/support review | Official body is 11 x 11 x 6.6 mm; PCB land pattern remains provisional | Check Mouser/DigiKey Korea and Korean industrial distributors; secure samples before routing
Navigation cap | 1 | Low round concave thumb surface | Custom 14 mm 3D-printed fit-check cap | Qualified molded cap after shaft drawing review | Attachment to the RKJXM metal shaft remains provisional | Print several bore tolerances; do not press-fit onto an unsupported PCB
Adapter connector plug | 2 | Common-PCB mezzanine connection | Samtec TSW-110-07-G-D candidate | Qualified 2x10 2.54 mm header | Prototype-friendly; production may use lower-profile mezzanine | Domestic generic stock is easy; lock exact height before enclosure
Adapter connector socket | 1 | Common-PCB mezzanine connection | Samtec SSW-110-02-G-D candidate | Qualified 2x10 2.54 mm socket | Must mate with selected plug and support current | Use matching plated system
I2C pull-up | 2 | I2C bias | 4.7 kOhm 1% candidate | 2.2-10 kOhm after capacitance test | 0603 or 0805 | Exact value is a measurement output
MCP address/reset pull | 4 | Defined expander startup | 10 kOhm 1% candidate | 4.7-47 kOhm after review | 0603 or 0805 | Count/value may change with address/reset circuit
RGB data resistor | 1 | First-LED edge damping | 330 Ohm 1% | 220-470 Ohm after scope test | 0603 or 0805 close to first LED | Widely available
LED local capacitor | 12 | RGB decoupling | 100 nF X7R >=10 V | Manufacturer-qualified equivalent | 0603/0805 adjacent to each LED | Do not omit for prototype
Logic decoupling | 3 | IC supply decoupling | 100 nF X7R >=10 V | Manufacturer-qualified equivalent | One per active IC, close to pins | Final count follows schematic
RGB bulk capacitor | 1 | Low-profile LED transient reservoir | Panasonic 10TPF150ML, 150 uF 10 V | Qualified 100-220 uF polymer after transient review | Polar SMD 7.3 x 4.3 x 2.8 mm; draft footprint is EIA-7343-31 | Verify Panasonic land pattern, polarity, inrush, procurement, and actual height before fabrication
Local bulk capacitor | 2 | 3.3 V and LED rail support | 10 uF X7R >=10 V | 22 uF after derating review | 0805/1206 depending derating | Account for DC-bias loss
Touch tuning capacitor | 1 | Touch sensitivity | TBD from AT42QT1010 reference design | DNP value ladder for coupon | C0G/NP0 where appropriate | Populate after overlay coupon test
Battery connector | 1 per adapter | Protected Li-Po connection | JST S2B-PH-K-S(LF)(SN) candidate | JST B2B-PH-K-S(LF)(SN) | Side/vertical entry is mechanical decision; polarity must be documented | Commonly available but cable polarity is not universal
Battery | 1 | Portable power | Protected 3.7 V Li-Po, exact MPN TBD | Qualified protected cell fitting envelope | Capacity/dimensions/connector/charge rate must match | Purchase from reputable Korean battery supplier
Test points | 8+ | Power and signal bring-up | Keystone 5015 candidate or SMD loop/test pads | Fabricated PCB test pads | At least GND, VBUS, 3V3, BAT, RGB rail, SDA, SCL, IOX_INT | Use probe-accessible placement
Switch plate | 1 | Mechanical support | 1.5 mm prototype plate, material TBD | 3D-printed or laser-cut test plate | Thickness follows switch family | Prototype locally before final finish
Common PCB | 1 | All fixed inputs and RGB | 1.6 mm FR-4 prototype | Thickness adjusted only after stack review | Two-layer versus four-layer decided after RF/touch/layout review | Use Korean or regional quick-turn fab after DRC
MCU adapter PCB | 2 | Board-specific mapping | 1.6 mm FR-4 prototype | Thinner board after mechanical review | One design per MCU | Panelize only after both designs pass review

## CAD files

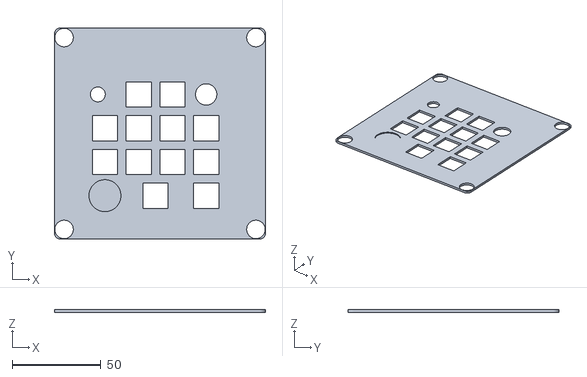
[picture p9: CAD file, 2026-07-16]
mechanical/exports/v1-fit-check/agent-deck-v1-mx-plate.stl
118.8 x 118.8 x 1.50

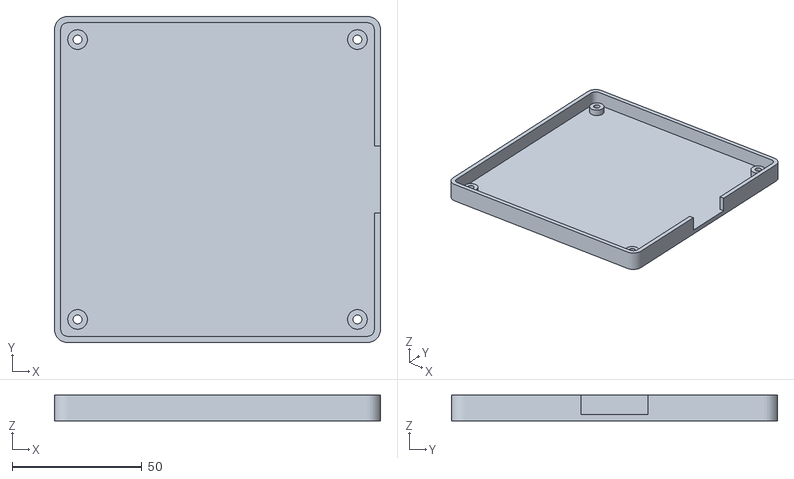
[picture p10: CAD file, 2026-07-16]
mechanical/exports/v1-fit-check/agent-deck-v1-bottom.stl
125.8 x 125.8 x 10.0

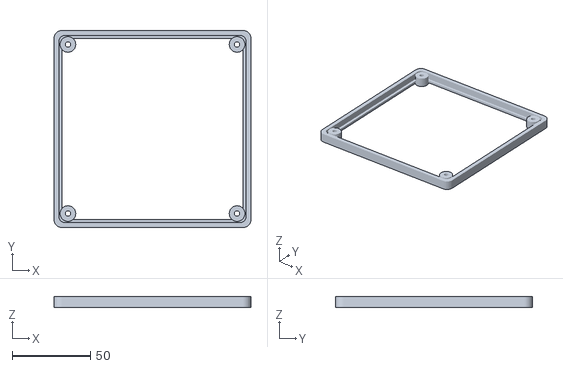
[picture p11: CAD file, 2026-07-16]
mechanical/exports/v1-fit-check/agent-deck-v1-top-bezel.stl
125.8 x 125.8 x 7.00

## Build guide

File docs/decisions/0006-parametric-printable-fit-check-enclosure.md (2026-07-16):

# ADR-0006: Build a parametric printable enclosure fit-check before mechanical freeze

Status: accepted for V1 prototype planning  
Date: 2026-07-16

## Decision

Create a three-piece, script-generated enclosure consisting of a bottom PCB tray, top perimeter bezel, and replaceable 1.5 mm MX plate. Derive all control and mounting coordinates from the current common PCB, export manifold STL files, and label the result as a fit-check rather than a production enclosure.

## Drivers

- A physical print reveals PCB, switch, touch, fastener, and connector problems earlier than a cosmetic shell alone.
- A replaceable plate allows the switch family, touch membrane, and control openings to change without discarding the tray.
- Parametric generation keeps PCB and enclosure datums reviewable in source control.
- Lowering C30 to a 2.8 mm candidate body makes a 17 mm enclosure body feasible without a local bulge.

## Constraints

- Exact switch/socket, keycap, encoder, navigation, adapter connector, USB cable, battery, and antenna envelopes are not frozen.
- The broad side opening is a service slot, not a final USB-C port.
- The 0.8 mm touch membrane and 14.2 mm MX cutouts require physical coupons and printer-specific compensation.
- The model assumes plastic plate/bezel material; metal plate RF and touch behavior requires a separate review.

## Rejected alternatives

- Cosmetic monolithic shell first: obscures fit problems and makes every mechanical change a full reprint.
- Final snap fits now: printer/process and assembly tolerances are unknown.
- Add a battery pocket from a guessed cell: would encode an unsafe unselected battery volume.

## Consequences

- Three STL files and machine-readable dimensions are available for a low-cost fit print.
- Enclosure source remains editable without proprietary CAD files.
- Production release remains blocked by the checklist in `mechanical/enclosure/README.md` and the hardware verification specification.

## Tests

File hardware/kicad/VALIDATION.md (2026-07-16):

# KiCad V1 draft validation

Validated with KiCad CLI 10.0.4 on 2026-07-16.

## Result

| Project | ERC | DRC violations | Unconnected | Interpretation |
| --- | ---: | ---: | ---: | --- |
| Common input PCB | 0 | 69 errors, 37 warnings | 115 | Square placement/netlist draft; not fabrication-ready |
| ESP32-S3 Plus adapter | 0 | 0 errors, 11 warnings | 15 | Placement/netlist draft; routing intentionally open |
| nRF52840 Plus adapter | 0 | 0 errors, 11 warnings | 15 | Placement/netlist draft; routing intentionally open |

The common-board errors are limited to the 12 reverse-mount SK6812 Mini-E footprints:

- 48 copper-to-local-cutout edge-clearance findings from KiCad's standard reverse-mount LED footprint.
- 21 courtyard overlaps because the reverse-mount LEDs intentionally sit under a key-envelope edge or between adjacent rows on the uniform 19 mm pitch.

No shorting-item or track-crossing finding remains. The remaining warnings are silkscreen/courtyard/library hygiene items expected in the placement draft.

## What passed

- All three `.kicad_sch` files parse and report zero ERC violations.
- All three `.kicad_pcb` files parse, refill copper zones, run DRC, and render through the KiCad CLI.
- The two adapter boards have zero DRC errors before routing.
- The main PCB has no reported shorting-item, inter-net clearance, hole-clearance, or track-crossing finding in its retained local matrix routing. `K11`'s column segment remains intentionally unrouted until the sample socket footprint is frozen.
- The common board outline, copper-zone inset, mounting holes, and enclosure source agree on an independent 118 mm × 118 mm PCB datum and the same top-side control map: encoder, two keys, navigation; four keys; four keys; touch, 2u PTT, auxiliary key.
- D16 is isolated as `BAT_SENSE_D16_RESERVED` on both adapters.

## Stop condition

Do not generate Gerbers or order boards from this revision. Release routing starts only after the exact switch/socket, five-way switch, adapter connector stack height, touch overlay, and plate geometry are locked. Before fabrication, all open connections must be routed, the LED cutout/land pattern must receive a documented rule review, and the required ERC/DRC/3D gates in `AGENTS.md` must pass.

## Reproduction

```sh
KICAD=/opt/homebrew/Caskroom/kicad/10.0.4/KiCad/KiCad.app/Contents/MacOS/kicad-cli

$KICAD sch erc hardware/kicad/input-main/input-main.kicad_sch
$KICAD pcb drc --refill-zones hardware/kicad/input-main/input-main.kicad_pcb
```

Repeat the commands for each project under `hardware/kicad/adapters/`.

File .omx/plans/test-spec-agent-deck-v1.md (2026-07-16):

# Agent Deck V1 verification specification

Status: provisional, executable after exact parts are selected  
Date: 2026-07-16

## Evidence format

Each test run records hardware revision, adapter revision, MCU board revision, firmware commit, bridge commit, host OS, instruments, supply voltage/current limit, test steps, raw observations, result, and linked logs or photos. A pass without this metadata is not release evidence.

## Test matrix

Every applicable test runs once with XIAO ESP32-S3 Plus and once with XIAO nRF52840 Plus. USB tests run on both. BLE tests run on both when supported by the selected stack. ESP32-S3 Wi-Fi tests are comparative and do not become a V1 product requirement automatically.

## A. Static hardware review

- A01: Cross-check every XIAO pad and adapter net against the exact official schematic revision.
- A02: Confirm D16 remains dedicated to the board battery-sense path.
- A03: Confirm ESP32-S3 strapping pins are not externally forced to invalid reset levels.
- A04: Confirm nRF52840 NFC pins are either unused or explicitly configured as GPIO.
- A05: Verify USB, antenna, switch, encoder, navigation switch, and battery mechanical clearances from 3D models.
- A06: KiCad ERC and DRC report zero unexplained errors.
- A07: Verify diode direction, hot-swap socket orientation, RGB pin 1, IC orientation, and connector keying from fabrication outputs.

## B. Power safety

- B01: With no MCU installed, apply current-limited 5 V and verify 5 V, switched RGB rail, and 3.3 V expectations.
- B02: Exercise USB-only, battery-only, USB-plus-battery, unpowered host, and disconnected battery cases; observe no reverse current outside component limits.
- B03: Toggle `RGB_PWR_EN` and verify the LED rail reaches its off target and powers up without resetting the MCU.
- B04: Command worst-case RGB output, verify hardware current limiting, then verify normal firmware clamps output to the declared budget.
- B05: Measure sleep, idle connected, active input, BLE connected, Wi-Fi connected where applicable, and representative 13-LED state currents.
- B06: Run 30 minutes active and 2 hours idle without unexplained reset, over-temperature, or rail drift.
- B07: Verify battery voltage read against a calibrated meter at at least three cell voltages; follow each board's documented enable sequence.

## C. Inputs

- C01: Each of 12 keys produces only its assigned key ID across 100 actuations.
- C02: Defined two-key and three-key combinations show no ghost input; diode orientation is verified if any failure occurs.
- C03: A rapid 10-second key test does not leave a logically stuck key after release.
- C04: Rotate the encoder 200 detents in each direction at normal speed and 50 detents rapidly; compare reported delta to physical count.
- C05: Press the encoder 100 times without false rotation exceeding the documented tolerance.
- C06: Each navigation contact produces the correct event across 100 actuations; simultaneous contacts follow the documented rejection/priority rule.
- C07: Touch tap, long press, and double tap each reach at least 95% recognition in a 20-trial scripted human test after calibration.
- C08: Touch does not self-trigger during representative RGB switching, USB traffic, enclosure contact, or charger connection tests.
- C09: K11 press starts one host-side push-to-talk session, release stops it, and lost transport/heartbeat also stops it without leaving capture active.

## D. RGB

- D01: Address each of 12 LEDs independently with red, green, blue, and off, and confirm the physical key-to-index map.
- D02: Verify logical agent states map to the documented palette and selected-agent indication.
- D03: Disconnect/reconnect transport while LEDs are active; stale state expires to a safe disconnected pattern.
- D04: Verify brightness limit persists across reboot and cannot exceed the firmware current budget.
- D05: Command all 12 LEDs simultaneously at maximum requested white and verify the transmitted frame is scaled or clamped to the declared aggregate current budget before the hardware limiter intervenes.

## E. USB and BLE

- E01: USB HID keyboard enumerates with stable report descriptors and sends a non-destructive test key.
- E02: Vendor HID capability request and protocol ping complete after cold boot and reset.
- E03: Composite USB reconnects after 20 unplug/replug cycles without manual reflashing.
- E04: BLE HID bonds, disconnects, and reconnects after host sleep and device reset.
- E05: Custom GATT state update and input event round-trip without duplicate sequence acceptance.
- E06: Transport loss causes no buffered destructive action to execute after reconnection.
- E07: If USB and BLE are both connected, the ownership policy prevents duplicate host actions.

## F. Protocol and bridge

- F01: Firmware and bridge golden vectors encode and decode every message type identically.
- F02: Unknown version, unknown message type, oversized length, invalid enum, stale sequence, and malformed payload are rejected safely.
- F03: The bridge maps fixture inputs to all six normalized agent states plus `unknown/disconnected` behavior.
- F04: Session selection remains stable while the tmux list changes and rejects a stale session identifier.
- F05: Restarting the bridge causes capability renegotiation and a full state resync.
- F06: Codex, Hermes, OMX, and tmux integrations are isolated adapters; one parser failure does not crash the transport loop.

## G. Dangerous actions

- G01: Approve succeeds only while the selected session is in `waiting_approval` and the configured confirmation gesture completes.
- G02: Reject succeeds only in a compatible pending state.
- G03: Interrupt targets the selected running session and requires an acknowledgement or explicit timeout state.
- G04: Push, deploy, and delete cannot be bound to an unconfirmed short press.
- G05: A session change between button-down and confirmation cancels the pending action.
- G06: Device reset, bridge reset, duplicate packet, and reconnect do not replay a dangerous action.

## H. Mechanical endurance smoke tests

- H01: Plate and enclosure support encoder and navigation switch actuation without visible PCB pad flex.
- H02: Perform 500 actuations each on the encoder click, navigation center, and one representative key; inspect solder joints and mounting tabs.
- H03: USB cable insertion/removal does not lift or twist the adapter beyond the enclosure support allowance.
- H04: Battery and antenna remain retained after normal handling and enclosure reassembly.

## MCU selection scorecard

Record measured values and score 1–5 for:

- BLE reconnect success and latency
- USB enumeration/recovery
- Active and idle current
- Estimated battery life from measured duty cycle
- Protocol/transport implementation complexity
- Debugging and update recovery
- Wi-Fi value versus power cost
- Host bridge complexity
- Available GPIO headroom and adapter complexity
- Observed faults over the complete test matrix

Do not select the final MCU from advertised specifications alone.

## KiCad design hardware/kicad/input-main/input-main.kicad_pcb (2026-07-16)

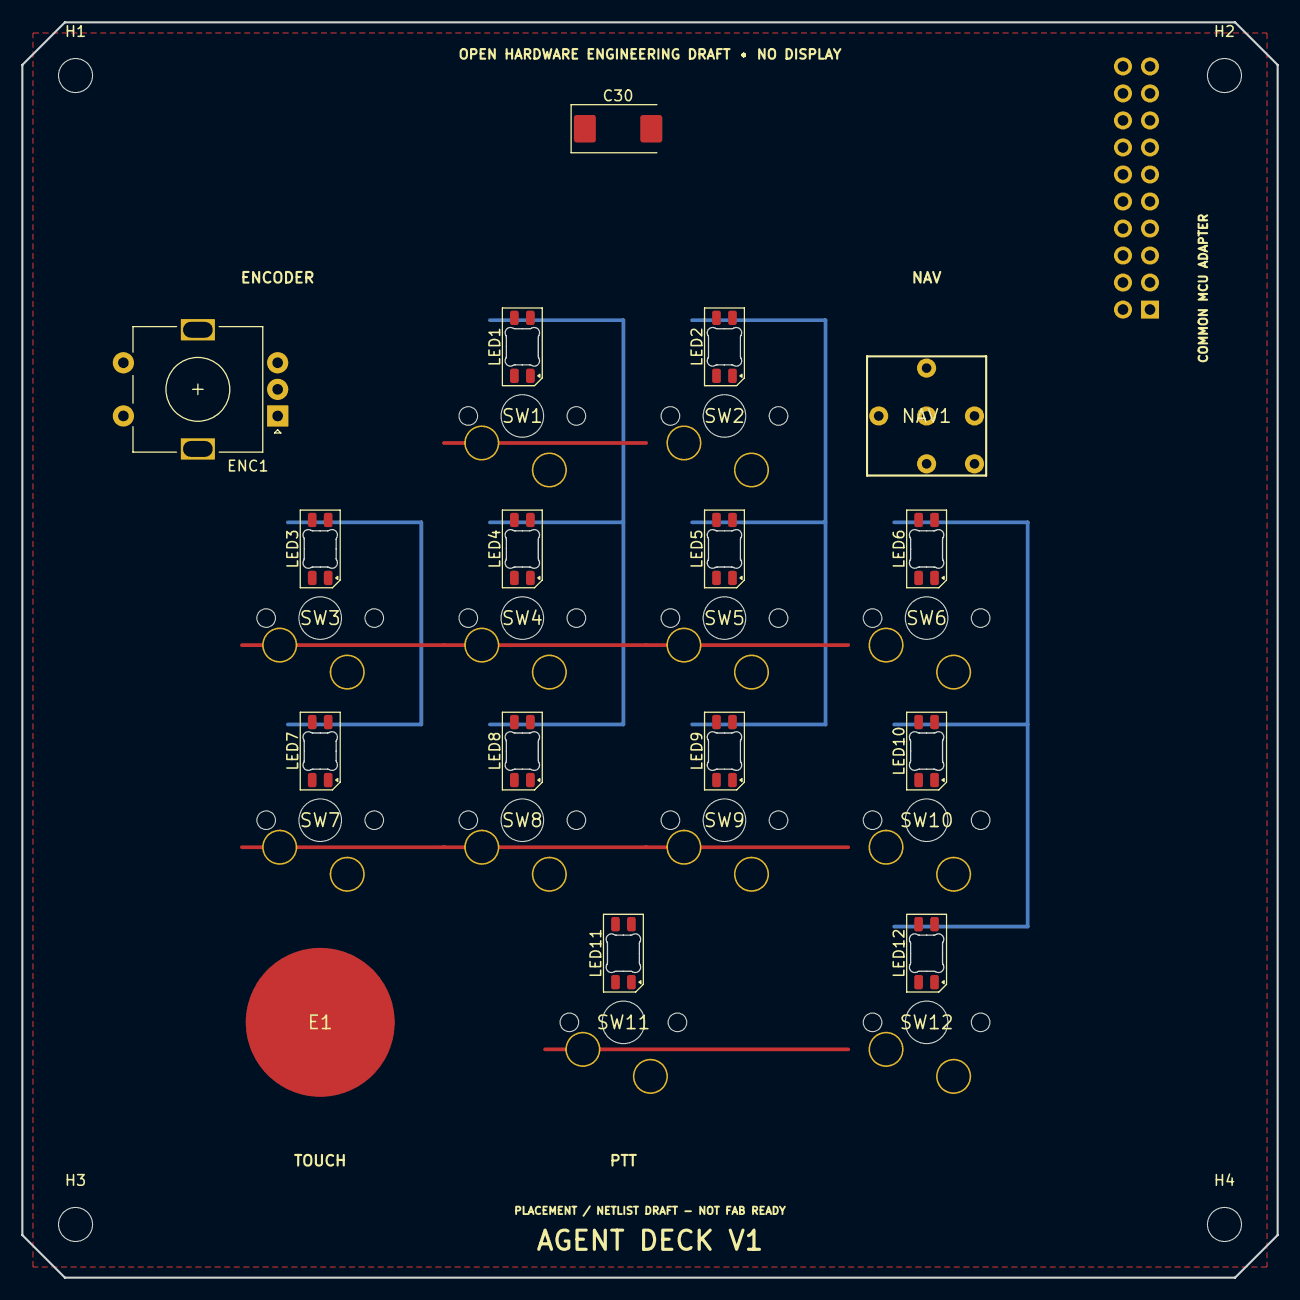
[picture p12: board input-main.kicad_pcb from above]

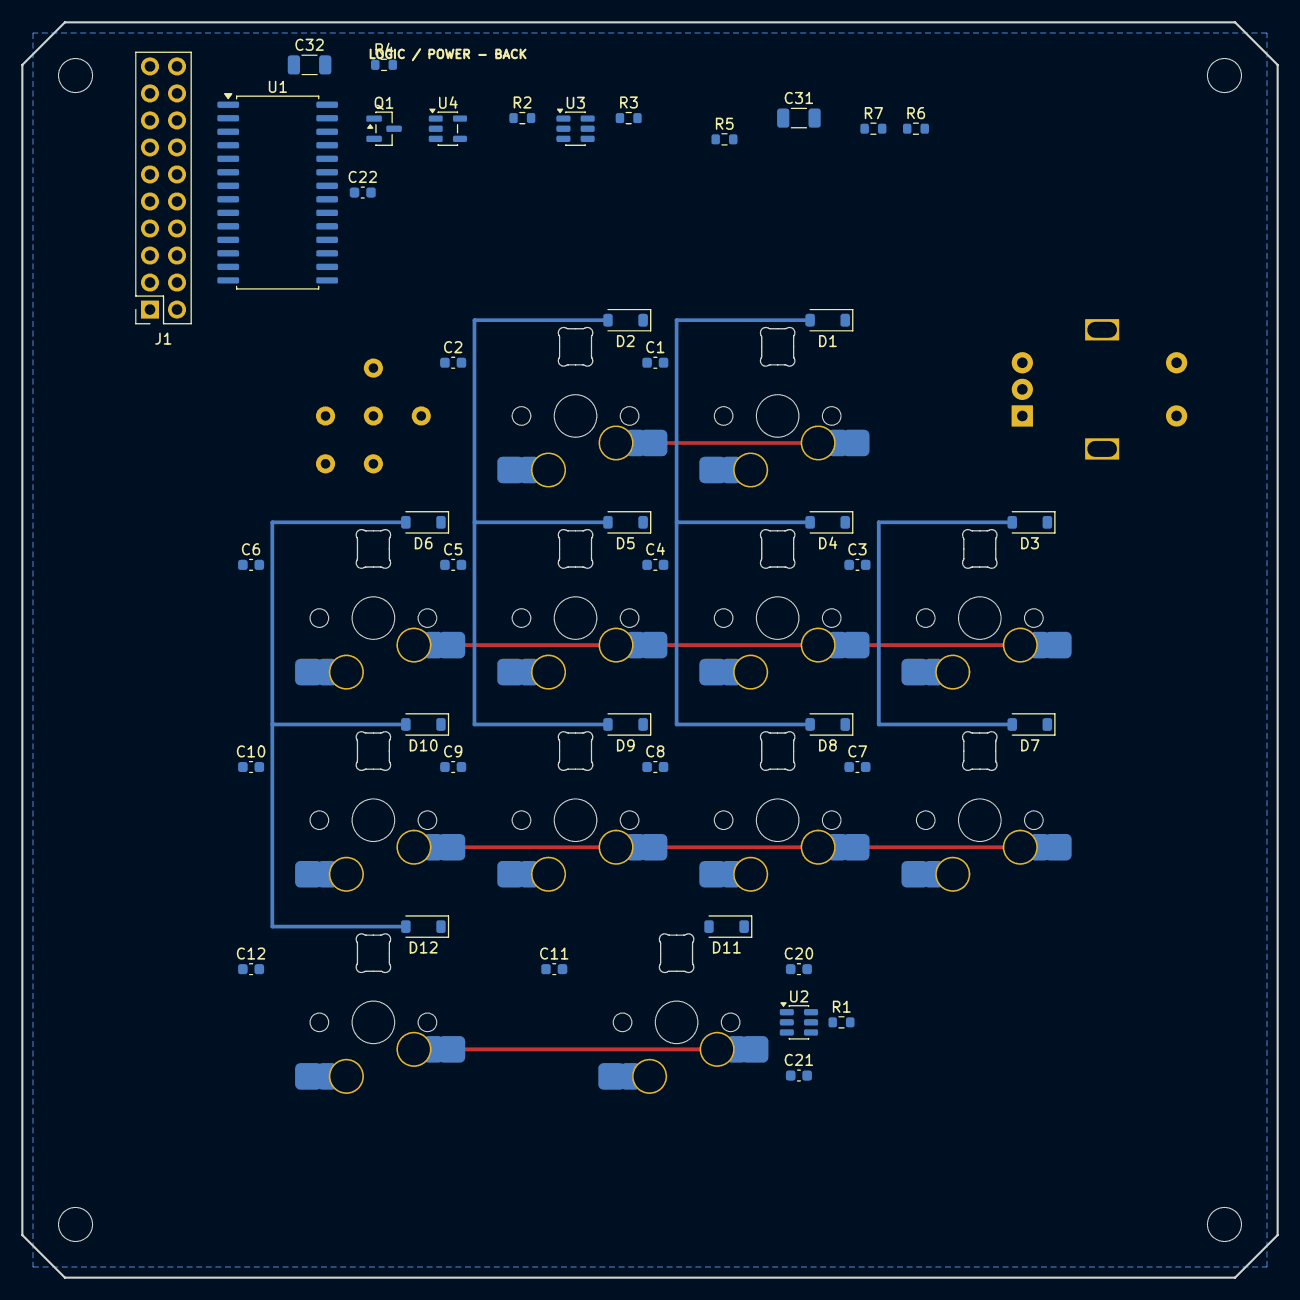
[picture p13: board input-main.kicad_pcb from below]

Board: 2 copper layers, 118.0 x 118.0 mm, 74 parts (42 on the bottom side), 58 nets.

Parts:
C1, C2, C3, C4, C5, C6, C7, C8, C9, C10, C11, C12: 100nF LED local; C_0603_1608Metric
C20: 10nF C0G touch candidate; C_0603_1608Metric
C21: 100nF; C_0603_1608Metric
C22: 100nF MCP23017; C_0603_1608Metric
C30: 150uF 10V low-profile polymer candidate; CP_EIA-7343-31_Kemet-D
C31: 10uF 10V X7R LED rail; C_1206_3216Metric
C32: 10uF 10V X7R 3V3 rail; C_1206_3216Metric
D1, D2, D3, D4, D5, D6, D7, D8, D9, D10, D11, D12: 1N4148W; D_SOD-123
E1: 14 mm circular touch electrode; Touch_Electrode_14mm
ENC1: EC11E15244G1 candidate; RotaryEncoder_Alps_EC11E-Switch_Vertical_H20mm
H1, H2, H3, H4: M3; MountingHole_3.2mm_M3
J1: COMMON_MCU_ADAPTER_2x10; PinSocket_2x10_P2.54mm_Vertical
LED1, LED2, LED3, LED4, LED5, LED6, LED7, LED8, LED9, LED10, LED11, LED12: SK6812MINI-E; LED_SK6812MINI-E_3.2x2.8mm_P1.5mm_ReverseMount
NAV1: RKJXM1015004 low-profile stick candidate / land p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; Nav_RKJXM1015004_ELECTRICAL_PLACEHOLDER
Q1: MMBT3904 RGB OE inverter; SOT-23
R1: 1k touch series; R_0603_1608Metric
R2: 232k 1% ILIM (~117mA typ); R_0603_1608Metric
R3: 100k EN pulldown; R_0603_1608Metric
R4: 10k OE pullup; R_0603_1608Metric
R5: 330R RGB data; R_0603_1608Metric
R6: 4.7k SDA pullup; R_0603_1608Metric
R7: 4.7k SCL pullup; R_0603_1608Metric
SW1, SW2, SW3, SW4, SW5, SW6, SW7, SW8, SW9, SW10, SW12: MX 1u hot-swap / CPG151101S11-16; MX_1u_Kailh_CPG151101S11-16_Hotswap
SW11: MX 2u PTT hot-swap / stabilizer TBD / CPG151101S1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; MX_1u_Kailh_CPG151101S11-16_Hotswap
U1: MCP23017-E/SO; SOIC-28W_7.5x17.9mm_P1.27mm
U2: AT42QT1010-TSHR; SOT-23-6
U3: TPS2553DBVR; SOT-23-6
U4: SN74AHCT1G125DBVR; SOT-23-5

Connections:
+3V3: C21.1, C22.1, C32.1, J1.1, R6.1, R7.1, U1.9, U1.18, U2.5
COL0: D3.2, D7.2, U1.25
COL1: D1.2, D4.2, D8.2, D11.2, U1.26
COL2: D2.2, D5.2, D9.2, U1.27
COL3: D6.2, D10.2, D12.2, U1.28
ENC_A: ENC1.A, J1.10
ENC_B: ENC1.B, J1.11
ENC_SW: ENC1.S1, J1.12
GND: C1.2, C2.2, C3.2, C4.2, C5.2, C6.2, C7.2, C8.2, C9.2, C10.2, C11.2, C12.2, C21.2, C22.2, C30.2, C31.2, C32.2, ENC1.C, ENC1.S2, J1.2, J1.4, J1.17, J1.18, J1.19, J1.20, LED1.3, LED2.3, LED3.3, LED4.3, LED5.3, LED6.3, LED7.3, LED8.3, LED9.3, LED10.3, LED11.3, LED12.3, NAV1.6, Q1.2, R2.2, R3.2, U1.10, U1.15, U1.16, U1.17, U2.2, U2.6, U3.2, U4.3
I2C_SCL: J1.6, R7.2, U1.12
I2C_SDA: J1.5, R6.2, U1.13
IOX_INT: J1.7, U1.19
K1_D: D1.1, SW1.2
K2_D: D2.1, SW2.2
K3_D: D3.1, SW3.2
K4_D: D4.1, SW4.2
K5_D: D5.1, SW5.2
K6_D: D6.1, SW6.2
K7_D: D7.1, SW7.2
K8_D: D8.1, SW8.2
K9_D: D9.1, SW9.2
K10_D: D10.1, SW10.2
K11_D: D11.1, SW11.2
K12_D: D12.1, SW12.2
LED_5V: C1.1, C2.1, C3.1, C4.1, C5.1, C6.1, C7.1, C8.1, C9.1, C10.1, C11.1, C12.1, C30.1, C31.1, LED1.1, LED2.1, LED3.1, LED4.1, LED5.1, LED6.1, LED7.1, LED8.1, LED9.1, LED10.1, LED11.1, LED12.1, U3.6
NAV_CENTER_N: NAV1.5, U1.5
NAV_DOWN_N: NAV1.2, U1.2
NAV_LEFT_N: NAV1.3, U1.3
NAV_RIGHT_N: NAV1.4, U1.4
NAV_UP_N: NAV1.1, U1.1
RGB_BUF_OUT: R5.1, U4.4
RGB_DATA: J1.8, U4.2
RGB_DIN0: LED1.4, R5.2
RGB_ILIM: R2.1, U3.5
RGB_LINK1: LED1.2, LED2.4
RGB_LINK2: LED2.2, LED3.4
RGB_LINK3: LED3.2, LED4.4
RGB_LINK4: LED4.2, LED5.4
RGB_LINK5: LED5.2, LED6.4
RGB_LINK6: LED6.2, LED7.4
RGB_LINK7: LED7.2, LED8.4
RGB_LINK8: LED8.2, LED9.4
RGB_LINK9: LED9.2, LED10.4
RGB_LINK10: LED10.2, LED11.4
RGB_LINK11: LED11.2, LED12.4
RGB_OE_N: Q1.3, R4.1, U4.1
RGB_PWR_EN: J1.9, Q1.1, R3.1, U3.3
ROW0: SW1.1, SW2.1, U1.21
ROW1: SW3.1, SW4.1, SW5.1, SW6.1, U1.22
ROW2: SW7.1, SW8.1, SW9.1, SW10.1, U1.23
ROW3: SW11.1, SW12.1, U1.24
SPARE0: J1.15, U1.7
SPARE1: J1.16, U1.8
TOUCH_ELECTRODE: E1.1, R1.1
TOUCH_OUT: U1.6, U2.1
TOUCH_SNS: C20.2, U2.4
TOUCH_SNSK: C20.1, R1.2, U2.3
VBUS_5V: J1.3, R4.2, U3.1, U4.5

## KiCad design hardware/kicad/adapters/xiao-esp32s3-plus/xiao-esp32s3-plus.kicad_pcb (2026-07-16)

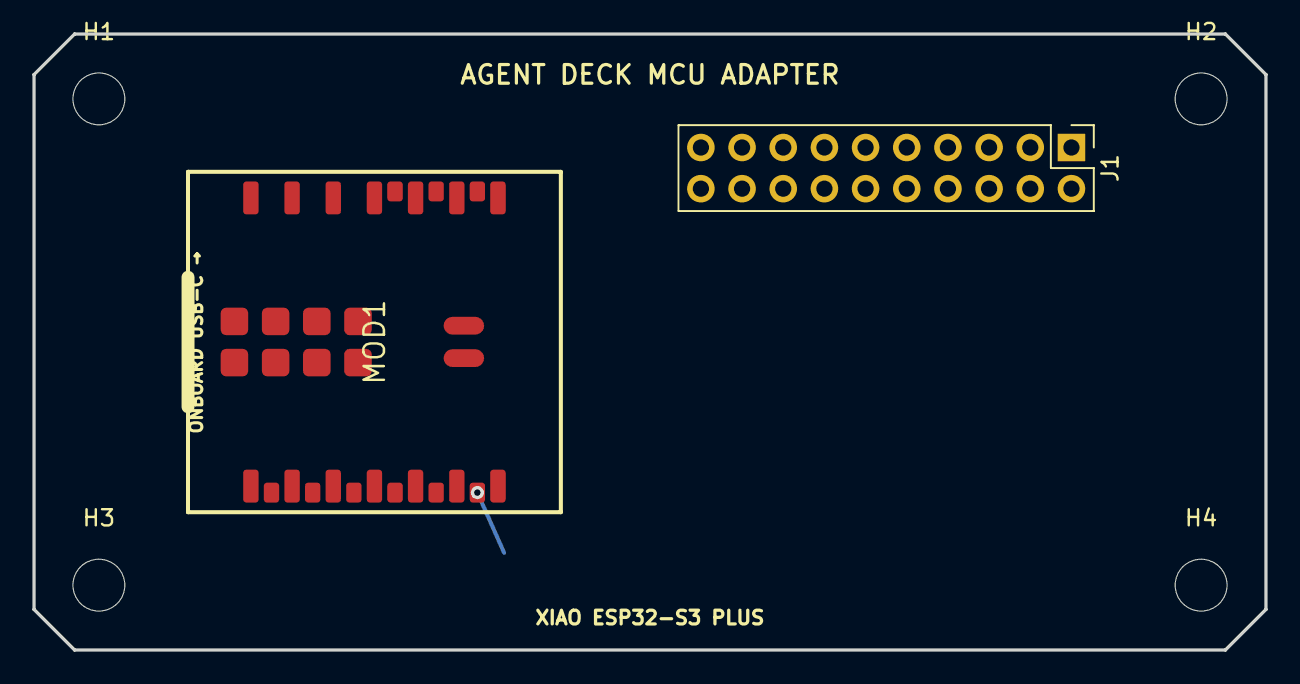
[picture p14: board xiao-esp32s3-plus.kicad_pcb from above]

Board: 2 copper layers, 76.0 x 38.0 mm, 7 parts (1 on the bottom side), 14 nets.

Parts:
H1, H2, H3, H4: M3; MountingHole_3.2mm_M3
J1: COMMON_MCU_ADAPTER_2x10; PinHeader_2x10_P2.54mm_Vertical
MOD1: XIAO ESP32-S3 PLUS; XIAO_Plus_Official_Base_Pattern
TP1: D16 reserved; TestPoint_Pad_D1.5mm

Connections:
+3V3: J1.1, MOD1.12
BAT_SENSE_D16_RESERVED: MOD1.20, TP1.1
ENC_A: J1.10, MOD1.9
ENC_B: J1.11, MOD1.10
ENC_SW: J1.12, MOD1.11
GND: J1.2, J1.4, J1.17, J1.18, J1.19, J1.20, MOD1.13, MOD1.27, MOD1.33
I2C_SCL: J1.6, MOD1.6
I2C_SDA: J1.5, MOD1.5
IOX_INT: J1.7, MOD1.2
RGB_DATA: J1.8, MOD1.1
RGB_PWR_EN: J1.9, MOD1.4
UART_RX_DBG: J1.14, MOD1.8
UART_TX_DBG: J1.13, MOD1.7
VBUS_5V: J1.3, MOD1.14

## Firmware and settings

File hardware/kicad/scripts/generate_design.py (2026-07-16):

#!/usr/bin/env python3
"""Generate the Agent Deck V1 KiCad engineering draft.

Run this script with KiCad's bundled Python interpreter.  The generated boards
are intentionally reproducible: the common input PCB contains the complete V1
electrical net assignment, while the two adapter boards isolate board-specific
XIAO pin mappings.

This is an engineering draft, not fabrication release data.  The exact MX
switch/socket, navigation switch, connector stack height, and touch tuning
values remain mechanical/electrical validation inputs.
"""

from __future__ import annotations

import json
import math
import sys
import uuid
from pathlib import Path

import pcbnew


ROOT = Path(__file__).resolve().parents[3]
KICAD_ROOT = Path("/opt/homebrew/Caskroom/kicad/10.0.4/KiCad/KiCad.app/Contents/SharedSupport")
FP_ROOT = KICAD_ROOT / "footprints"
OUT_ROOT = ROOT / "hardware" / "kicad"
RENDER_ROOT = ROOT / "artifacts" / "renders"


def mm(value: float) -> int:
    return pcbnew.FromMM(value)


def pt(x: float, y: float) -> pcbnew.VECTOR2I:
    return pcbnew.VECTOR2I(mm(x), mm(y))


def xy(position: pcbnew.VECTOR2I) -> tuple[float, float]:
    return pcbnew.ToMM(position.x), pcbnew.ToMM(position.y)


def ensure_dirs() -> None:
    for path in (
        OUT_ROOT / "input-main",
        OUT_ROOT / "adapters" / "xiao-esp32s3-plus",
        OUT_ROOT / "adapters" / "xiao-nrf52840-plus",
        OUT_ROOT / "libraries" / "agent-deck.pretty",
        RENDER_ROOT,
    ):
        path.mkdir(parents=True, exist_ok=True)


def add_net(board: pcbnew.BOARD, name: str) -> pcbnew.NETINFO_ITEM:
    net = pcbnew.NETINFO_ITEM(board, name)
    board.Add(net)
    return net


def net_map(board: pcbnew.BOARD, names: list[str]) -> dict[str, pcbnew.NETINFO_ITEM]:
    return {name: add_net(board, name) for name in names}


def load_footprint(lib: str, name: str) -> pcbnew.FOOTPRINT:
    footprint = pcbnew.FootprintLoad(str(FP_ROOT / f"{lib}.pretty"), name)
    if footprint is None:
        raise RuntimeError(f"Unable to load footprint {lib}:{name}")
    return footprint


def place_footprint(
    board: pcbnew.BOARD,
    footprint: pcbnew.FOOTPRINT,
    reference: str,
    value: str,
    x: float,
    y: float,
    *,
    angle: float = 0,
    back: bool = False,
) -> pcbnew.FOOTPRINT:
    footprint.SetReference(reference)
    footprint.SetValue(value)
    footprint.SetPosition(pt(x, y))
    footprint.SetOrientationDegrees(angle)
    board.Add(footprint)
    if back:
        footprint.Flip(footprint.GetPosition(), False)
    try:
        footprint.Reference().SetVisible(True)
        footprint.Value().SetVisible(False)
    except AttributeError:
        pass
    return footprint


def assign_pads(
    footprint: pcbnew.FOOTPRINT,
    nets: dict[str, pcbnew.NETINFO_ITEM],
    assignments: dict[str, str | None],
) -> None:
    for pad in footprint.Pads():
        number = pad.GetNumber()
        if number in assignments and assignments[number] is not None:
            pad.SetNet(nets[assignments[number]])


def pad_by_number(footprint: pcbnew.FOOTPRINT, number: str) -> pcbnew.PAD:
    for pad in footprint.Pads():
        if pad.GetNumber() == number:
            return pad
    raise KeyError(f"{footprint.GetReference()} has no pad {number}")


def add_track(
    board: pcbnew.BOARD,
    net: pcbnew.NETINFO_ITEM,
    start: tuple[float, float] | pcbnew.VECTOR2I,
    end: tuple[float, float] | pcbnew.VECTOR2I,
    *,
    layer: int = pcbnew.B_Cu,
    width: float = 0.25,
) -> pcbnew.PCB_TRACK:
    track = pcbnew.PCB_TRACK(board)
    track.SetNet(net)
    track.SetLayer(layer)
    track.SetWidth(mm(width))
    track.SetStart(start if isinstance(start, pcbnew.VECTOR2I) else pt(*start))
    track.SetEnd(end if isinstance(end, pcbnew.VECTOR2I) else pt(*end))
    board.Add(track)
    return track


def add_path(
    board: pcbnew.BOARD,
    net: pcbnew.NETINFO_ITEM,
    points: list[tuple[float, float] | pcbnew.VECTOR2I],
    *,
    layer: int = pcbnew.B_Cu,
    width: float = 0.25,
) -> None:
    for start, end in zip(points, points[1:]):
        add_track(board, net, start, end, layer=layer, width=width)


def add_via(
    board: pcbnew.BOARD,
    net: pcbnew.NETINFO_ITEM,
    position: tuple[float, float] | pcbnew.VECTOR2I,
    *,
    diameter: float = 0.8,
    drill: float = 0.4,
) -> pcbnew.PCB_VIA:
    via = pcbnew.PCB_VIA(board)
    via.SetNet(net)
    via.SetPosition(position if isinstance(position, pcbnew.VECTOR2I) else pt(*position))
    via.SetWidth(mm(diameter))
    via.SetDrill(mm(drill))
    via.SetLayerPair(pcbnew.F_Cu, pcbnew.B_Cu)
    board.Add(via)
    return via


def add_board_line(
    board: pcbnew.BOARD,
    start: tuple[float, float],
    end: tuple[float, float],
    *,
    layer: int = pcbnew.Edge_Cuts,
    width: float = 0.2,
) -> None:
    line = pcbnew.PCB_SHAPE(board)
    line.SetShape(pcbnew.SHAPE_T_SEGMENT)
    line.SetStart(pt(*start))
    line.SetEnd(pt(*end))
    line.SetLayer(layer)
    line.SetWidth(mm(width))
    board.Add(line)


def add_rect_outline(board: pcbnew.BOARD, left: float, top: float, right: float, bottom: float, chamfer: float = 3.0) -> None:
    points = [
        (left + chamfer, top),
        (right - chamfer, top),
        (right, top + chamfer),
        (right, bottom - chamfer),
        (right - chamfer, bottom),
        (left + chamfer, bottom),
        (left, bottom - chamfer),
        (left, top + chamfer),
        (left + chamfer, top),
    ]
    for start, end in zip(points, points[1:]):
        add_board_line(board, start, end)


def add_text(
    board: pcbnew.BOARD,
    text_value: str,
    x: float,
    y: float,
    *,
    layer: int = pcbnew.F_SilkS,
    size: float = 1.2,
    thickness: float = 0.2,
    angle: float = 0,
) -> pcbnew.PCB_TEXT:
    text = pcbnew.PCB_TEXT(board)
    text.SetText(text_value)
    text.SetPosition(pt(x, y))
    text.SetLayer(layer)
    text.SetTextSize(pt(size, size))
    text.SetTextThickness(mm(thickness))
    text.SetTextAngleDegrees(angle)
    if layer in (pcbnew.B_SilkS, pcbnew.B_Cu, pcbnew.B_Fab):
        text.SetMirrored(True)
    board.Add(text)
    return text


def add_zone(
    board: pcbnew.BOARD,
    net: pcbnew.NETINFO_ITEM,
    layer: int,
    points: list[tuple[float, float]],
    *,
    clearance: float = 0.25,
    min_thickness: float = 0.25,
) -> pcbnew.ZONE:
    zone = pcbnew.ZONE(board)
    zone.SetLayer(layer)
    zone.SetNet(net)
    zone.SetLocalClearance(mm(clearance))
    zone.SetMinThickness(mm(min_thickness))
    zone.SetPadConnection(pcbnew.ZONE_CONNECTION_FULL)
    outline = zone.Outline()
    outline.NewOutline()
    for x, y in points:
        outline.Append(mm(x), mm(y))
    board.Add(zone)
    return zone


def add_mounting_hole(board: pcbnew.BOARD, reference: str, x: float, y: float) -> pcbnew.FOOTPRINT:
    fp = load_footprint("MountingHole", "MountingHole_3.2mm_M3")
    return place_footprint(board, fp, reference, "M3", x, y)


def add_smd_pad(
    footprint: pcbnew.FOOTPRINT,
    number: str,
    x: float,
    y: float,
    sx: float,
    sy: float,
    *,
    shape: int = pcbnew.PAD_SHAPE_ROUNDRECT,
    layer: int = pcbnew.F_Cu,
    paste: bool = True,
    mask: bool = True,
) -> pcbnew.PAD:
    pad = pcbnew.PAD(footprint)
    pad.SetNumber(number)
    pad.SetAttribute(pcbnew.PAD_ATTRIB_SMD)
    pad.SetShape(shape)
    pad.SetSize(pt(sx, sy))
    pad.SetPosition(pt(x, y))
    layers = pcbnew.LSET()
    layers.AddLayer(layer)
    if paste:
        layers.AddLayer(pcbnew.F_Paste if layer == pcbnew.F_Cu else pcbnew.B_Paste)
    if mask:
        layers.AddLayer(pcbnew.F_Mask if layer == pcbnew.F_Cu else pcbnew.B_Mask)
    pad.SetLayerSet(layers)
    if shape == pcbnew.PAD_SHAPE_ROUNDRECT:
        pad.SetRoundRectRadiusRatio(0.2)
    footprint.Add(pad)
    return pad


def add_npth_pad(
    footprint: pcbnew.FOOTPRINT,
    x: float,
    y: float,
    drill: float,
) -> pcbnew.PAD:
    pad = pcbnew.PAD(footprint)
    pad.SetNumber("")
    pad.SetAttribute(pcbnew.PAD_ATTRIB_NPTH)
    pad.SetShape(pcbnew.PAD_SHAPE_CIRCLE)
    pad.SetSize(pt(drill, drill))
    pad.SetDrillSize(pt(drill, drill))
    pad.SetPosition(pt(x, y))
    pad.SetLayerSet(pad.PTHMask())
    footprint.Add(pad)
    return pad


def add_th_pad(
    footprint: pcbnew.FOOTPRINT,
    number: str,
    x: float,
    y: float,
    diameter: float = 2.0,
    drill: float = 1.0,
    *,
    shape: int = pcbnew.PAD_SHAPE_CIRCLE,
) -> pcbnew.PAD:
    pad = pcbnew.PAD(footprint)
    pad.SetNumber(number)
    pad.SetAttribute(pcbnew.PAD_ATTRIB_PTH)
    pad.SetShape(shape)
    pad.SetSize(pt(diameter, diameter))
    pad.SetDrillSize(pt(drill, drill))
    pad.SetPosition(pt(x, y))
    pad.SetLayerSet(pad.PTHMask())
    footprint.Add(pad)
    return pad


def add_fp_line(
    footprint: pcbnew.FOOTPRINT,
    start: tuple[float, float],
    end: tuple[float, float],
    *,
    layer: int = pcbnew.F_SilkS,
    width: float = 0.2,
) -> None:
    line = pcbnew.PCB_SHAPE(footprint)
    line.SetShape(pcbnew.SHAPE_T_SEGMENT)
    line.SetStart(pt(*start))
    line.SetEnd(pt(*end))
    line.SetLayer(layer)
    line.SetWidth(mm(width))
    footprint.Add(line)


def make_mx_hotswap_footprint() -> pcbnew.FOOTPRINT:
    """Centered MX footprint with a north-facing Kailh CPG151101S11-16 socket.

    The socket is mounted on the PCB back.  Its body sits north of the switch
    center so the reverse-mount RGB package can remain south of the stem.
    """

    fp = pcbnew.FOOTPRINT(None)
    fp.SetFPIDAsString("AgentDeck:MX_1u_Kailh_CPG151101S11-16_Hotswap")
    fp.SetReference("SW1")
    fp.SetValue("MX hot-swap / Kailh CPG151101S11-16")

    # 14 mm plate opening and 19.05 mm key envelope, centered on the PCB datum.
    # The opening belongs on a mechanical documentation layer; a full silk box
    # would cross the socket lands and create misleading DRC noise.
    for start, end in (
        ((-7.0, -7.0), (7.0, -7.0)),
        ((7.0, -7.0), (7.0, 7.0)),
        ((7.0, 7.0), (-7.0, 7.0)),
        ((-7.0, 7.0), (-7.0, -7.0)),
    ):
        add_fp_line(fp, start, end, layer=pcbnew.Dwgs_User, width=0.1)
    for start, end in (
        ((-9.4, -9.4), (9.4, -9.4)),
        ((9.4, -9.4), (9.4, 9.4)),
        ((9.4, 9.4), (-9.4, 9.4)),
        ((-9.4, 9.4), (-9.4, -9.4)),
    ):
        add_fp_line(fp, start, end, layer=pcbnew.F_CrtYd, width=0.05)

    # Five-pin MX mechanical holes.  The two switch-contact holes are enlarged
    # to the socket manufacturer's 3 mm recommendation and remain plated so
    # the socket pads and matrix nets are one inspectable electrical feature.
    add_npth_pad(fp, 0.0, 0.0, 4.0)
    add_npth_pad(fp, -5.08, 0.0, 1.75)
    add_npth_pad(fp, 5.08, 0.0, 1.75)
    add_th_pad(fp, "1", -3.81, 2.54, diameter=3.3, drill=3.0)
    add_th_pad(fp, "2", 2.54, 5.08, diameter=3.3, drill=3.0)

    # Back-side solder lands.  Copper-only bridge pads avoid depositing paste
    # into the switch-pin holes while retaining one net per contact.
    add_smd_pad(fp, "1", -5.635, 2.54, 1.65, 2.5, layer=pcbnew.B_Cu, paste=False, mask=False)
    add_smd_pad(fp, "1", -7.36, 2.54, 2.55, 2.5, layer=pcbnew.B_Cu)
    add_smd_pad(fp, "2", 4.34, 5.08, 1.65, 2.5, layer=pcbnew.B_Cu, paste=False, mask=False)
    add_smd_pad(fp, "2", 6.09, 5.08, 2.55, 2.5, layer=pcbnew.B_Cu)

    # Approximate socket body envelope for bottom-side placement review.
    for start, end in (
        ((-6.1, 0.85), (4.9, 0.85)),
        ((4.9, 0.85), (4.9, 6.75)),
        ((4.9, 6.75), (-6.1, 6.75)),
        ((-6.1, 6.75), (-6.1, 0.85)),
    ):
        add_fp_line(fp, start, end, layer=pcbnew.B_Fab, width=0.15)
    return fp


def make_navigation_footprint() -> pcbnew.FOOTPRINT:
    """Electrical placeholder; the RKJXM official land pattern is not frozen."""
    fp = pcbnew.FOOTPRINT(None)
    fp.SetFPIDAsString("AgentDeck:Nav_RKJXM1015004_ELECTRICAL_PLACEHOLDER")
    fp.SetReference("NAV1")
    fp.SetValue("RKJXM1015004 candidate - transcribe official land pattern")
    for number, x, y in (
        ("1", 0, -4.5),
        ("2", 0, 4.5),
        ("3", -4.5, 0),
        ("4", 4.5, 0),
        ("5", 0, 0),
        ("6", 4.5, 4.5),
    ):
        add_th_pad(fp, number, x, y, 1.8, 0.9)
    for start, end in (
        ((-5.6, -5.6), (5.6, -5.6)),
        ((5.6, -5.6), (5.6, 5.6)),
        ((5.6, 5.6), (-5.6, 5.6)),
        ((-5.6, 5.6), (-5.6, -5.6)),
    ):
        add_fp_line(fp, start, end)
    return fp


def make_touch_electrode() -> pcbnew.FOOTPRINT:
    fp = pcbnew.FOOTPRINT(None)
    fp.SetFPIDAsString("AgentDeck:Touch_Electrode_14mm")
    fp.SetReference("E1")
    fp.SetValue("14 mm circular touch electrode")
    add_smd_pad(fp, "1", 0, 0, 14.0, 14.0, shape=pcbnew.PAD_SHAPE_CIRCLE)
    return fp


def make_testpoint(reference: str, value: str) -> pcbnew.FOOTPRINT:
    fp = load_footprint("TestPoint", "TestPoint_Pad_D1.5mm")
    fp.SetReference(reference)
    fp.SetValue(value)
    return fp


def make_xiao_plus_footprint() -> pcbnew.FOOTPRINT:
    """Physical pad pattern transcribed from Seeed's official Plus baseboard."""
    fp = pcbnew.FOOTPRINT(None)
    fp.SetFPIDAsString("AgentDeck:XIAO_Plus_Official_Base_Pattern")
    fp.SetReference("MOD1")
    fp.SetValue("Seeed XIAO Plus (official base pattern)")
    fp.SetAllowSolderMaskBridges(True)

    left_outer_y = (-7.62, -5.08, -2.54, 0, 2.54, 5.08, 7.62)
    right_outer_y = (7.62, 5.08, 2.54, 0, -2.54, -5.08, -7.62)
    for number, y in enumerate(left_outer_y, start=1):
        add_smd_pad(fp, str(number), -8.89, y, 2.032, 0.95)
    for number, y in enumerate(right_outer_y, start=8):
        add_smd_pad(fp, str(number), 8.89, y, 2.032, 0.95)

    for number, y in zip(range(15, 21), (-6.35, -3.81, -1.27, 1.27, 3.81, 6.35)):
        add_smd_pad(fp, str(number), -9.29, y, 1.232, 0.95)
    for number, y in zip(range(21, 24), (6.35, 3.81, 1.27)):
        add_smd_pad(fp, str(number), 9.29, y, 1.232, 0.95)

    for number, x, y in (
        (24, -1.27, -8.636),
        (25, 1.27, -8.636),
        (26, -1.27, -6.096),
        (27, 1.27, -6.096),
        (28, -1.27, -3.556),
        (29, 1.27, -3.556),
        (30, -1.27, -1.016),
        (31, 1.27, -1.016),
    ):
        add_smd_pad(fp, str(number), x, y, 1.7, 1.7)
    pad32 = add_smd_pad(fp, "32", -0.994, 5.518, 2.5, 1.1, shape=pcbnew.PAD_SHAPE_OVAL)
    pad33 = add_smd_pad(fp, "33", 1.006, 5.518, 2.5, 1.1, shape=pcbnew.PAD_SHAPE_OVAL)
    pad32.SetOrientationDegrees(270)
    pad33.SetOrientationDegrees(270)

    outline = [(-10.5, -11.5), (10.5, -11.5), (10.5, 11.5), (-10.5, 11.5), (-10.5, -11.5)]
    for start, end in zip(outline, outline[1:]):
        add_fp_line(fp, start, end, layer=pcbnew.F_SilkS, width=0.25)
    add_fp_line(fp, (-4, -11.5), (4, -11.5), layer=pcbnew.F_SilkS, width=0.8)
    return fp
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

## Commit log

2026-07-15 Establish a clean foundation for the OpenAI Micro clone
    Constraint: Technology stack and product scope are intentionally undecided
    Rejected: Framework-specific scaffolding | It would prematurely lock the project into an unrequested stack
    Confidence: high
    Scope-risk: narrow
    Directive: Choose the application stack before adding generated framework files
    Tested: Verified Git initialization, tracked starter files, and clean worktree
    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
2026-07-15 Give the hardware clone an evidence-backed V1 design contract
    Constraint: The original product internals are unpublished and the two XIAO Plus boards cannot be assumed electrically interchangeable
    Rejected: A direct shared XIAO socket | It hides board-specific USB, battery, boot, NFC, JTAG, and ADC differences
    Scope-risk: moderate
    Directive: Complete firmware and transport spikes before releasing the schematic, and recheck exact purchased board revisions against official sources
    Tested: Git diff whitespace check, Markdown local-link validation, YAML parse, CSV shape validation, official pin-source cross-check, and clean document reference scan
    Not-tested: No schematic, PCB,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
    [prototype-bom.csv]
2026-07-15 Make the physical controller reviewable before mechanical freeze
    Constraint: Keep unreleased OpenAI Micro internals outside the design and preserve MCU-specific adapters
    Rejected: Automatic long-route completion | DRC exposed genuine crossings before mechanical inputs were locked
    Scope-risk: broad
    Directive: Do not generate Gerbers until hardware/kicad/VALIDATION.md stop condition is cleared
    Tested: KiCad 10.0.4 parsed and rendered all boards; ERC 0 on all schematics; adapters DRC 0 errors; main has only documented LED footprint errors
    Not-tested: Physical fit, full routing, USB/BLE firmware, battery, and first-article electrical tests
    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
    [input-main.kicad_pcb, input-main.kicad_sch, prototype-bom.csv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]
2026-07-15 Let every control key communicate agent state without more MCU pins
    Constraint: Preserve RGB_DATA and RGB_PWR_EN allocation and the provisional 120 mA aggregate budget
    Rejected: Raise the hardware current limit now | Optical, USB-budget, transient, and thermal measurements are not available
    Directive: Do not increase RGB current or release Gerbers until the 13-key optical stack and all-white clamp tests pass
    Tested: KiCad generator completed; LED1-LED13 chain and C1-C13 asserted; all three schematic ERCs report 0; renders inspected; DRC debt recorded
    Not-tested: Physical keycap illumination, full routing, touch-noise immunity, thermal behavior, and first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
    [input-main.kicad_pcb, input-main.kicad_sch, prototype-bom.csv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]
2026-07-16 Make the physical control surface serviceable and printable
    Constraint: Preserve an independent public-exterior reference without asserting unpublished OpenAI Micro internals.
    Rejected: Soldered switches, a square navigation cap, a tall radial bulk capacitor, and the isolated lower-right K13 placement.
    Directive: Keep this revision out of fabrication until socket, navigation, touch, USB, battery, and first-article fit gates pass.
    Tested: KiCad 10.0.4 ERC on all projects; DRC with no short, copper-clearance, hole-clearance, or crossing findings; 13-key/13-LED geometry assertions; Blender 5.1.2 manifold STL generation and visual render review.
    Not-tested: Phy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
    [agent-deck-v1-bottom.stl, agent-deck-v1-mx-plate.stl, agent-deck-v1-top-bezel.stl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]
2026-07-16 Make the controller read as a compact square instrument
    Constraint: Preserve standard MX pitch and independent engineering dimensions while following only the public square product language.
    Rejected: A square cosmetic shell around the rectangular PCB and uniform scaling that would distort 19 mm switch pitch.
    Directive: Treat 118 mm as a prototype datum, not an inferred Codex Micro dimension; keep fabrication blocked until component and first-article gates pass.
    Tested: KiCad 10.0.4 ERC on all projects; DRC with no short, copper-clearance, hole-clearance, or crossing findings; 118 mm PCB endpoint assertions; 13-key/13-LED coordinate assertions; Blender 5.1.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
    [agent-deck-v1-bottom.stl, agent-deck-v1-mx-plate.stl, agent-deck-v1-top-bezel.stl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]
2026-07-16 Align the physical controls with the observable Codex layout
    The square controller now uses twelve hot-swap MX keys so the upper-right position belongs to the navigation control, while K11 remains a wide host-side push-to-talk control.
    Constraint: Preserve independent circuitry and avoid claims about unpublished Codex Micro internals
    Rejected: Keep a thirteenth MX key in the top row | it displaced the joystick from the observable layout
    Directive: Add K11 stabilizer geometry only from the selected part drawing before fabrication
    Tested: KiCad ERC on three projects; KiCad DRC and renders on three boards; Blender manifold checks and top-view visual i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
    [agent-deck-v1-mx-plate.stl, input-main.kicad_pcb, input-main.kicad_sch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]
2026-07-16 Make the key surface read as one coherent status grid
    The blank black-smoke keycaps now share one material and a 19 mm lattice, while K11 keeps PTT semantics without permanent artwork.
    Constraint: Preserve the 12-key public-facing control map and independent protocol semantics
    Rejected: Keep the microphone glyph or colored accents | both broke the uniform configurable key surface
    Directive: Qualify actual translucent keycap material and K11 stabilizer from physical samples before fabrication
    Tested: Blender manifold generation and top/assembled visual inspection; 1.8 mm gap calculation; KiCad ERC on all projects; main/adapter DRC; KiCad renders; gi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
    [agent-deck-v1-mx-plate.stl, input-main.kicad_pcb, xiao-esp32s3-plus.kicad_pcb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]
